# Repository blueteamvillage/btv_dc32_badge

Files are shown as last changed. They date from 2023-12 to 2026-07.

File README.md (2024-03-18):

# btv_dc32_badge

BTV DC32 Badge Artifacts

This is a DEFCON Indie badge created for DC32.

This is where all the files for the BTV DC32 Badge will be stored.

This includes code and art and cad and fab files.  All the things.

## File Structure

This is the file structure of this repository

* [/](/README.md) - YOU ARE HERE
* [/art/](./art/) - Artwork and other graphics created by this project
  * [/art/inspiration/](./art/inspiration/) - Art and graphics pulled f6 other sources used as inspiration for this project
  * [/art/fonts/](./art/fonts/) - Fonts used in art and graphics
* [/code/](./code/) - All project related Code / Firmware
* [/docs/](./docs/) - Documentation created by this project including web pages
* [/eda/](./eda/) - Electronic Design Automation files (i.e. KiCad)
  * [/eda/camera_badge/](./eda/camera_badge/) - KiCad 7.x project folder for the camera_badge PCB
* [/reference_parts/](./reference_parts/) - Documentation pulled from other sources related to components
* [/README.md](/README.md) - This File
* [/LICENSE](/LICENSE) - Currently set to MIT

Note: the reference_parts directory is a link to a submodule repository.
To add it use the following cmd after cloning this:
```
git submodule update --init --recursive
```
If adding for the first time (i.e., it is not linked in the remote master) use this:
```
git submodule add https://github.com/gowenrw/reference_parts reference_parts
```
This will make a link to the current commit of that repo.
To update it to a newer commit after its been added use this cmd:
```
git submodule update --remote
```

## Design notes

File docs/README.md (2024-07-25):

# BTV Camera Badge

BTV Camera Badge Repository web page and documentation.

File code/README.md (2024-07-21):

# Code

This is where all the project related Code / Firmware is located

# File Structure

This is the file structure of this repository

* [/](/README.md) - Home
* [/code/](/code/) - YOU ARE HERE

# Arduino IDE/CLI

The code presented here is mostly Arduino code.

In order to use this code and push new code to the ESP32 on the badge we recommend using the Arduino IDE/CLI software.
This can be downloaded for various platforms at [arduino.cc](https://www.arduino.cc/en/software).

The Arduino IDE UI will require some manual configuration to work with the badge ESP32 and our code.

The Arduino CLI can be used instead and allows for scripting much of the initial setup and use of whichever IDE you like (in my case I use VSCode).

# Arduino Versions

These are the Arduino IDE and CLI versions we have tested the code with:

* Arduino IDE v 2.3.2
  * [Windows MSI Link](https://downloads.arduino.cc/arduino-ide/arduino-ide_2.3.2_Windows_64bit.msi)
  * [Linux 64bit AppImage Link](https://downloads.arduino.cc/arduino-ide/arduino-ide_2.3.2_Linux_64bit.AppImage)
  * [MacOS ARM64bit DMG Link](https://downloads.arduino.cc/arduino-ide/arduino-ide_2.3.2_macOS_arm64.dmg)
  * [Installation Instructions](https://docs.arduino.cc/software/ide-v2/tutorials/getting-started/ide-v2-downloading-and-installing)
* Arduino CLI v 0.35.3
  * [Windows MSI Link](https://github.com/arduino/arduino-cli/releases/download/v0.35.3/arduino-cli_0.35.3_Windows_64bit.msi)
  * [Linux 64bit Tarball Link](https://github.com/arduino/arduino-cli/releases/download/v0.35.3/arduino-cli_0.35.3_Linux_64bit.tar.gz)
  * [MacOS ARM64bit Tarball Link](https://github.com/arduino/arduino-cli/releases/download/v0.35.3/arduino-cli_0.35.3_macOS_ARM64.tar.gz)
  * [Installation Instructions](https://arduino.github.io/arduino-cli/0.35/installation/)

WARNING - DO NOT use Arduino CLI v 1.x if you want the scripts here to work, it is very buggy concerning local config files and relative paths

# Quickstart

If you want to jump right in and start compiling and uploading code using the Arduino CLI and the scripts provided then checkout the [QUICKSTART page](QUICKSTART.md).

# Arduino IDE setup and use

Some additional setup is required to use the Arduino IDE with the ESP32 on the badge:

* Add the ESP32 boards manager URL in preferences
  * Under File->Preferences find the "Additional boards manager URLs" section and add the following
  * https://espressif.github.io/arduino-esp32/package_esp32_index.json
  * Then click OK and close the IDE.  When it is reopened it wil download the ESP32 board definitions.
* Select the board "ESP32 Dev Module"
  * You need to select a board to associate with the code even if that board is not connected
  * In the "Select Board" dropdown, choose "ESP32 Dev Module" from the list
  * The first time you do this it may download some addiotional software.
* Connect the ESP32 via USB cable and select the COM port if it is not autodetected
  * In most cases it should autodetect the port
  * Sometimes on first connect you need to help it by going to Tools->Port and choosing the port
* This code exceeds the normal partition size so make sure you select the Minimal SPIFFS Partition type
  * This setting can be found under Tools -> Partition Scheme
* This code uses the AdaFruit NeoPixel library which needs to be installed
  * The library can be installed via the Arduino IDE library manager or manually
  * Installation instructions can be found at [the adafruit neopixel github page](https://github.com/adafruit/Adafruit_NeoPixel)

Once the Arduino IDE environment has been set up you can simply open one of the sketches here, make whatever changes you like, then compile and upload the code to the badge.

# Arduino CLI

In an effort to bring portability to the code here (since this is lacking in the Arduino 2.x IDE) we will be providing a local configuration file for the Arduino CLI and scripts to make use of it.

While we cannot ensure this will work on all systems, the files provided should at a minimum help you configure your local environment.

## Using the CLI Local Config

The arduino cli will use a global default config if a config file is not specified.

A local config file is provided named ```arduino-cli.yml``` which uses relative path references for the data and staging and build and user area that Arduino CLI should use.

These directories are local to the repository code directory and the CLI will install all its needed files here instead of in the various places it usually defualts to on differnt systems.

While this might duplicate many files on your system if they are already installed in default locations, it provides a consistent cross platform way of knowing exactly what libraries, headers, etc., that Arduino will use in the compilation of your code.

NOTE that the .gitignore for this repository has been set up to ignore the local directories used to store the core and library files to prevent these files from accidentally getting uploaded to github.

To use the Arduino CLI with this local config file simply add the ```--config-file arduino-cli.yml``` argument to each CLI command.

For example, the command below uses the local config file and will dump the current config to the screen
```
arduino-cli --config-file arduino-cli.yml config dump
```

## Setup for CLI

There are a few things that need to be done to setup the Arduino CLI for use with the badge ESP32 and our code.

The ESP32 board core files must be loaded as well as any libraries the code will use.

To simplify this setup we have created setup bash script named ```cli-setup.sh``` that can be run on Linux and Windows (via Git Bash for Windows).

To perform the CLI setup via the script execute it in the code directory
```
bash ./cli-setup.sh
```

This script will save any std_out and std_err output to a file named ```arduino_cli_setup.log``` which you can review if you are having issues.

To perform the CLI setup manually without this script you can use the commands outlined below.

### Installing the ESP32 board core for CLI

Since the config is specifying a third party core for the ESP32 we need to pull an initial index from it.  This search command will pull that index.
```
arduino-cli --config-file arduino-cli.yml core search esp32
```

Next we need to install the ESP32 board core files using this command.
```
arduino-cli --config-file arduino-cli.yml core install esp32:esp32
```

If the ESP32 board core files were already installed the above will simply say already installed.

To update the core file indexs to check for newer versions of previously installed cores, use the following command
```
arduino-cli --config-file arduino-cli.yml core update-index
```

To upgrade any previously installed cores use the following command
```
arduino-cli --config-file arduino-cli.yml core upgrade
```

### Installing the Neopixel Library

This code uses the AdaFruit NeoPixel library which needs to be installed

If this is the first time we are installing a library we will need the indexes so this search command will get them
```
arduino-cli --config-file arduino-cli.yml lib search 'Adafruit NeoPixel'
```

Next we need to install the Adafruit NeoPixel library files with this command
```
arduino-cli --config-file arduino-cli.yml lib install 'Adafruit NeoPixel'
```

If the Adafruit NeoPixel library files were already installed the above will simply say already installed.

To upgrade a previously installed version of this library use the following command
```
arduino-cli --config-file arduino-cli.yml lib upgrade 'Adafruit NeoPixel'
```

### Installing Other Libraries

In addition to the Neopixel Library above the CTF portion of our code requires a few more libraries.

These should be installed using the same steps as above.

This is the list of additional libraries needed

* "AsyncTCP"
* "ESPAsyncWebSrv"
* "DNSServer"

## Connect badge ESP32 board via CLI

The following command will dump a list of all available board cores installed
```
arduino-cli --config-file arduino-cli.yml board listall
```

Make sure the ESP32 we are using on the badge is in that list
```
  ESP32 Dev Module                 esp32:esp32:esp32
```

If it is not then retry the CLI setup to install the core files.

Next we will connect the badge ESP32 to our machine using a USB C cable
and check if the CLI can see it.

The following command will list all the connected boards the CLI sees
```
arduino-cli --config-file arduino-cli.yml board list
```

This will show the detected COM port and board type (which may be Unknown)
```
  Port Protocol Type                Board Name FQBN Core
  COM4 serial   Serial Port (USB)   Unknown
```

Don't worry if the board FQBN shows up as Unknown since we can set that

Take note of the COM port since we will need that to communicate with it later

## Compile code via CLI

At this point we should be ready to compile and upload code to the badge ESP32 board.

In the following examples we will be referencing the sketch ```camera_badge_rev01``` code so you will need to change this for whichever sketch you wish to use.

The following command will compile the named sketch for use with our board fqbn
```
arduino-cli --config-file arduino-cli.yml compile --fqbn esp32:esp32:esp32 --build-path _build --export-binaries camera_badge_rev01 --build-property build.partitions=min_spiffs --build-property upload.maximum_size=1966080
```

The arg ```--build-path _build``` is optional to have it put all build artifacts here instead of temp for ease of troubleshooting.

The arg ```--export-binaries``` will save the final binary files into ```<sketch_name>/build/<fqbn>/``` for use by upload.

The build property args ```--build-property build.partitions=min_spiffs --build-property upload.maximum_size=1966080``` make sure that the partition size and upload size are set properly.
Our code is THIC and wont fit in the default partition size.

When the CLI compile is run it should show you compile stats and/or errors similar to this
```
  Sketch uses 1827197 bytes (92%) of program storage space. Maximum is 1966080 bytes.
  Global variables use 48884 bytes (14%) of dynamic memory, leaving 278796 bytes for local variables.
  Maximum is 327680 bytes.
  Used library        Version Path
  Adafruit NeoPixel   1.11.0  .\code\libraries\Adafruit_NeoPixel
  WiFi                2.0.0   .\code\_data\packages\esp32\hardware\esp32\2.0.11\libraries\WiFi
  AsyncTCP            1.1.4   .\code\libraries\AsyncTCP
  DNSServer           2.0.0   .\code\_data\packages\esp32\hardware\esp32\2.0.11\libraries\DNSServer
  ESPAsyncWebSrv      1.2.6   .\code\libraries\ESPAsyncWebSrv
  FS                  2.0.0   .\code\_data\packages\esp32\hardware\esp32\2.0.11\libraries\FS
  Used platform Version Path
  esp32:esp32   2.0.11  .\code\_data\packages\esp32\hardware\esp32\2.0.11
```

### Script to Compile code via CLI

To simplify the above we have created a bash script named ```cli-compile.sh``` that takes a single command line argument of the sketch name.

To perform the compile via the script execute it in the code directory
```
bash ./cli-compile.sh camera_badge_rev01
```

## Upload code via CLI

Now we are ready to upload the binary we compiled to the badge ESP32 board.

Note that the binary file needed is saved to ```<sketch_name>/build/<fqbn>/``` and will be named ```<sketch_name>.ino.bin```
The code we have written here may include binaries which can be used without compiling and if you make changes and compile then these files should be overwritten.

The following command will upload the named sketch binary to the badge
```
arduino-cli --config-file arduino-cli.yml upload -p COM4 --fqbn esp32:esp32:esp32 --input-file camera_badge_rev01/build/esp32.esp32.esp32/camera_badge_rev01.ino.bin
```

NOTE: Saving the compiled binary in a defined place and uploading from an input file allows for quickly changing between different code without the need to compile each again.

It should show you upload stats and/or errors
```
  esptool.py v4.5.1
  Serial port COM4
  Connecting....
  Chip is ESP32-D0WD-V3 (revision v3.0)
  Features: WiFi, BT, Dual Core, 240MHz, VRef calibration in efuse, Coding Scheme None
  Crystal is 40MHz
  MAC: a8:42:e3:47:f0:50
  Uploading stub...
  Running stub...
  Stub running...
  Changing baud rate to 921600
  Changed.
  Configuring flash size...
  Flash will be erased from 0x00001000 to 0x00005fff...
  ...
  Compressed 18960 bytes to 13073...
  Writing at 0x00001000... (100 %)
  Wrote 18960 bytes (13073 compressed) at 0x00001000 in 0.3 seconds (effective 538.9 kbit/s)...
  Hash of data verified.
  ...
  Compressed 732656 bytes to 475614...
  Writing at 0x00010000... (3 %)
  Writing at 0x0001c1bd... (6 %)
  ...
  Writing at 0x000bcec0... (96 %)
  Writing at 0x000c2b72... (100 %)
  Wrote 732656 bytes (475614 compressed) at 0x00010000 in 6.3 seconds (effective 925.8 kbit/s)...
  Hash of data verified.
  Leaving...
  Hard resetting via RTS pin...
```

### Script to Upload code via CLI

To simplify the above we have created a bash script named ```cli-upload.sh``` that takes two command line arguments of the sketch name and serial port.

To perform the compile via the script execute it in the code directory
```
bash ./cli-upload.sh camera_badge_rev01 COM4
```

## Monitor Serial Output

To monitor the serial output you can use the arduino-cli or your favorite serial app.

The following command will list all the connected boards so you can get the serial port
```
arduino-cli --config-file arduino-cli.yml board list
```

The arduino-cli monitor command with serial port (from above) and baud config can be used like this:
```
arduino-cli monitor --port COM4 --config baudrate=115200
```

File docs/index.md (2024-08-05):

---
layout: default
---

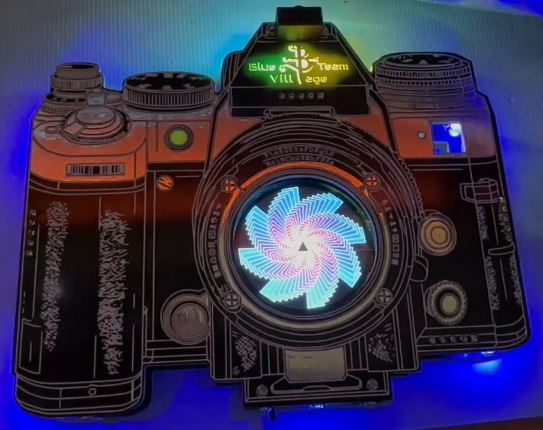
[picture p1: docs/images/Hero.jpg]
Hero Image


# BTV Camera Badge

Welcome to the BTV Camera Badge website.

This badge was designed for the DEFCON 32 security conference in August 2024.

On this page you will find all the details about this badge including an operations guide, an assembly guide (for those building the badge from a kit), and a detailed review of the art and cicuit design and pcb design.

---

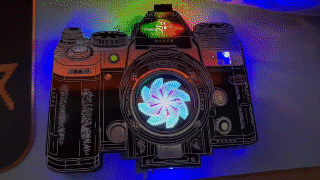
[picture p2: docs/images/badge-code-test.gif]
Code Test Image


# Details

[Assembly instructions can be found here](BadgeInstructions.md)

More detailed information about the project COMING SOON.

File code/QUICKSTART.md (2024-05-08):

# Code Quickstart

Notes:

* You will need Arduino CLI Installed and a Bash shell (on Windows Git Bash is provided by Git for Windows)
* The CTF code is a precompiled library so you cant change that for now, source to be released after defcon
* The current code that is loaded on the badge is the sketch named ```camera_badge_rev01```

## Setting up Arduino CLI environment

Follow these steps:

* Change directory to the code directory if you arent already there
* Run the following command preceding it with ```bash``` if needed by your OS
  * ```./cli-setup.sh```
* If it completes without errors then setup is complete
  * If you have errors then refer to the main README doc or script file to try the steps manually

## Compiling Code

Once you have made whatever changes you wanted to the code here is how we compile it.

* Change directory to the code directory if you arent already there
* Run the following command preceding it with ```bash``` if needed by your OS changing the sketch name if needed
  * ```./cli-compile.sh camera_badge_rev01```
* If it completes without errors then the compile is complete
  * If you have errors then read what they are and make the appropriate changes to your code

## Upload Code

Once the code has been compiled we can upload it to the badge.

Follow these steps:

* Change directory to the code directory if you arent already there
* Run the following command
  * ```arduino-cli --config-file arduino-cli.yml board list```
* Take note of the serial port name of the connected board 
* Run the following command preceding it with ```bash``` if needed and changing the serial port to above
  * ```./cli-upload.sh camera_badge_rev01 COM6```

## Serial Monitor

Once the code has been uploaded you can use the serial monitor to look for any text the code is sending.

* Run the following command changing the serial port to what board list showed above
  * ```arduino-cli monitor --config baudrate=115200 --port COM6```
* On Linux
  * ```arduino-cli --config-file arduino-cli.yml monitor --config baudrate=115200 --port /dev/ttyUSB0```

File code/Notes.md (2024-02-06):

Docs for the 1.28in round display

https://www.waveshare.com/wiki/1.28inch_LCD_Module

Video

https://www.youtube.com/watch?v=k2c2zCmC_X0&ab_channel=DroneBotWorkshop

Code screen_poc_01 uses waveshare example code

vcc 3.3v
gnd
scl 18
sda 23
dc 16
cs 5
rst 4

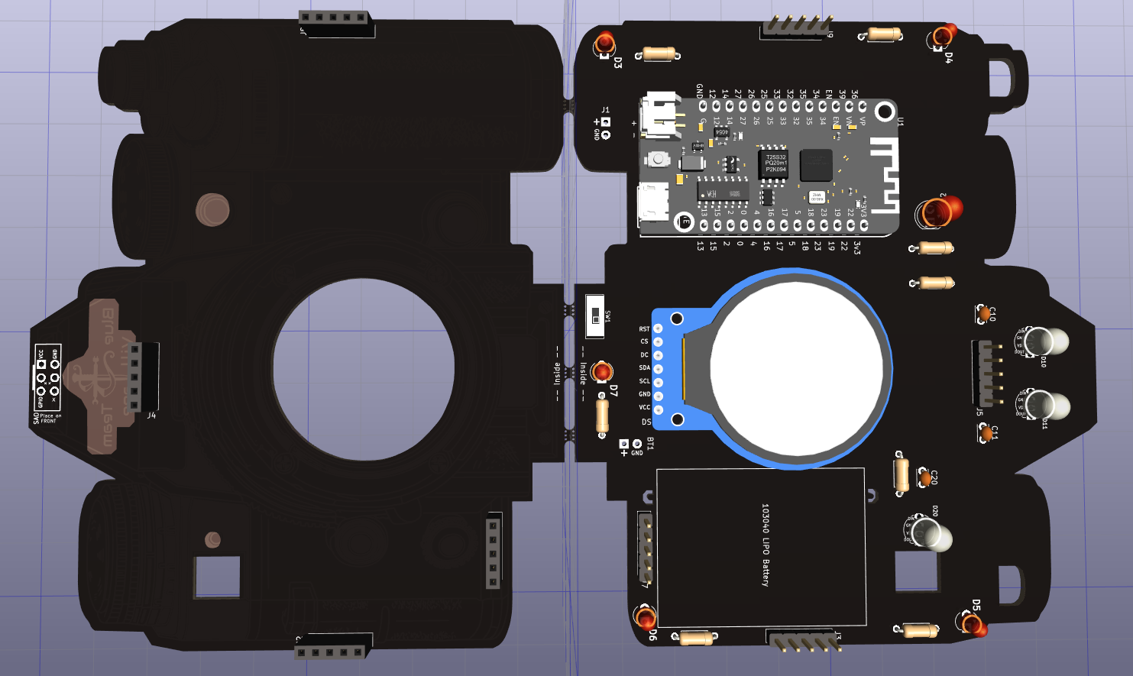
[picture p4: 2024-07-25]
docs/images/prototype-image03.png

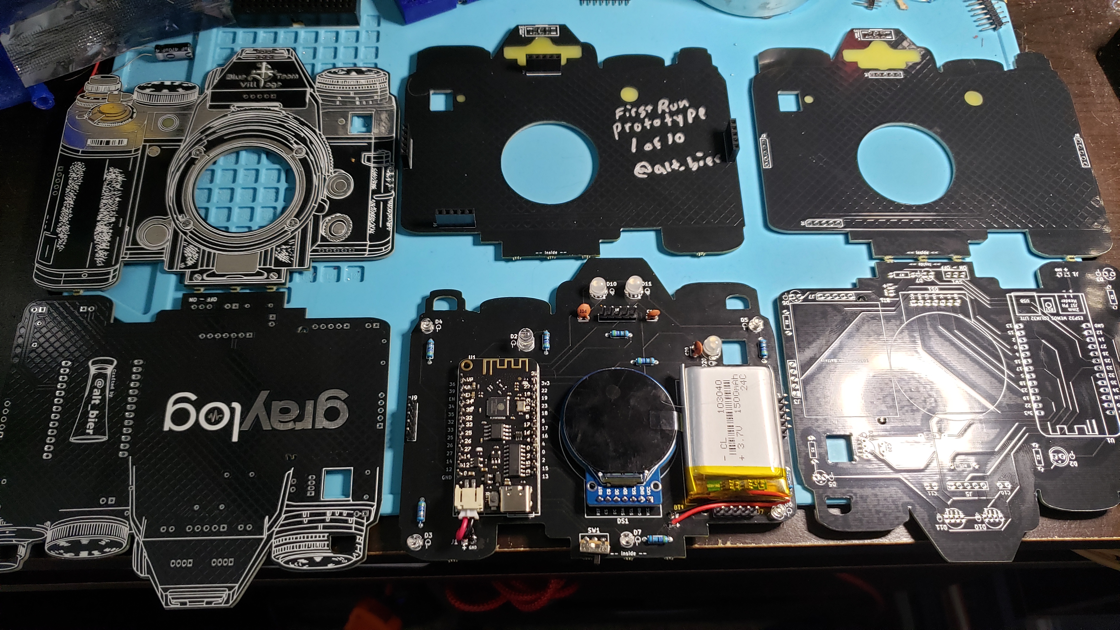
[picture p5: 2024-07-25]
docs/images/prototype-image04.jpg

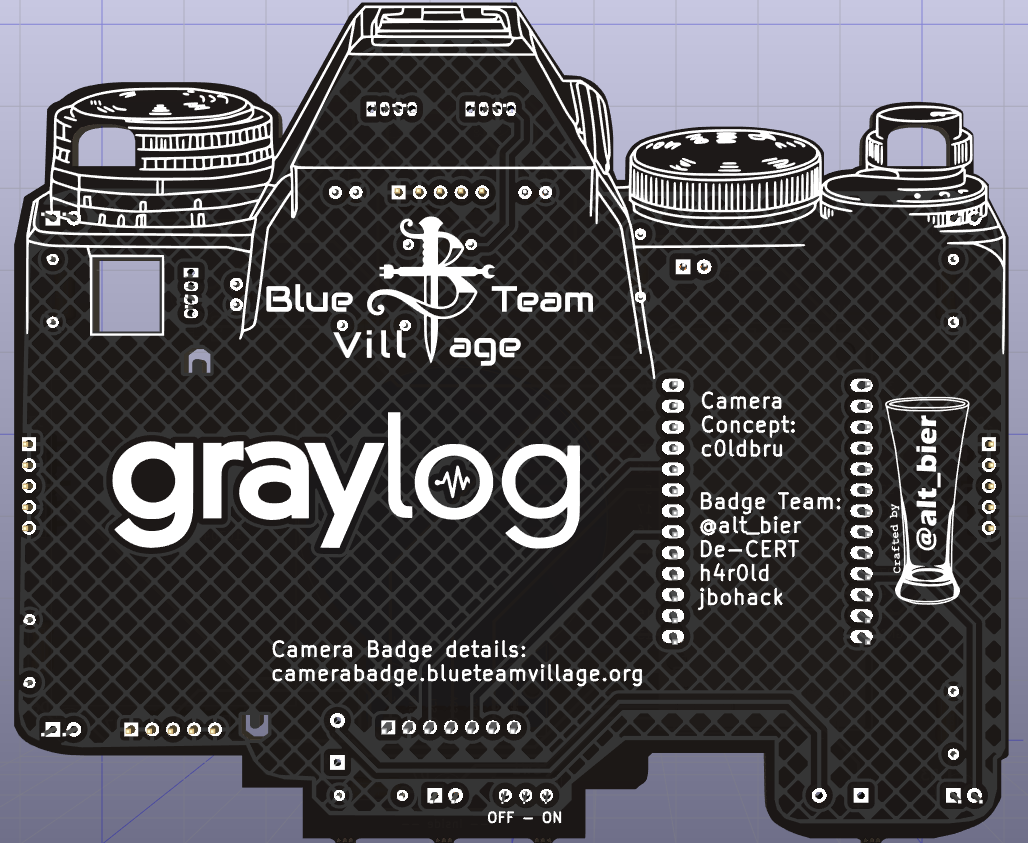
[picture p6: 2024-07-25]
docs/images/prototype-image02.png

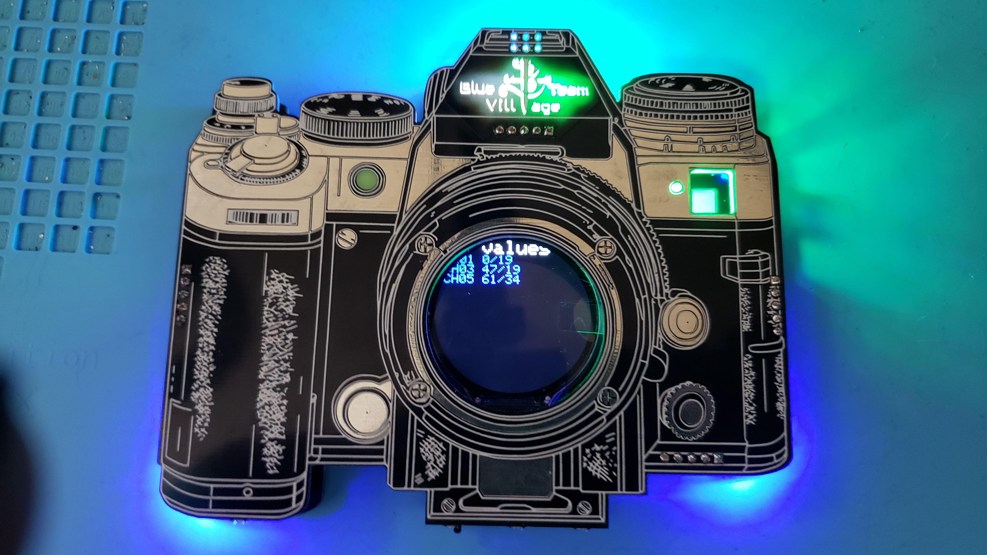
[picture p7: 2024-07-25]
docs/images/prototype-image05.jpg

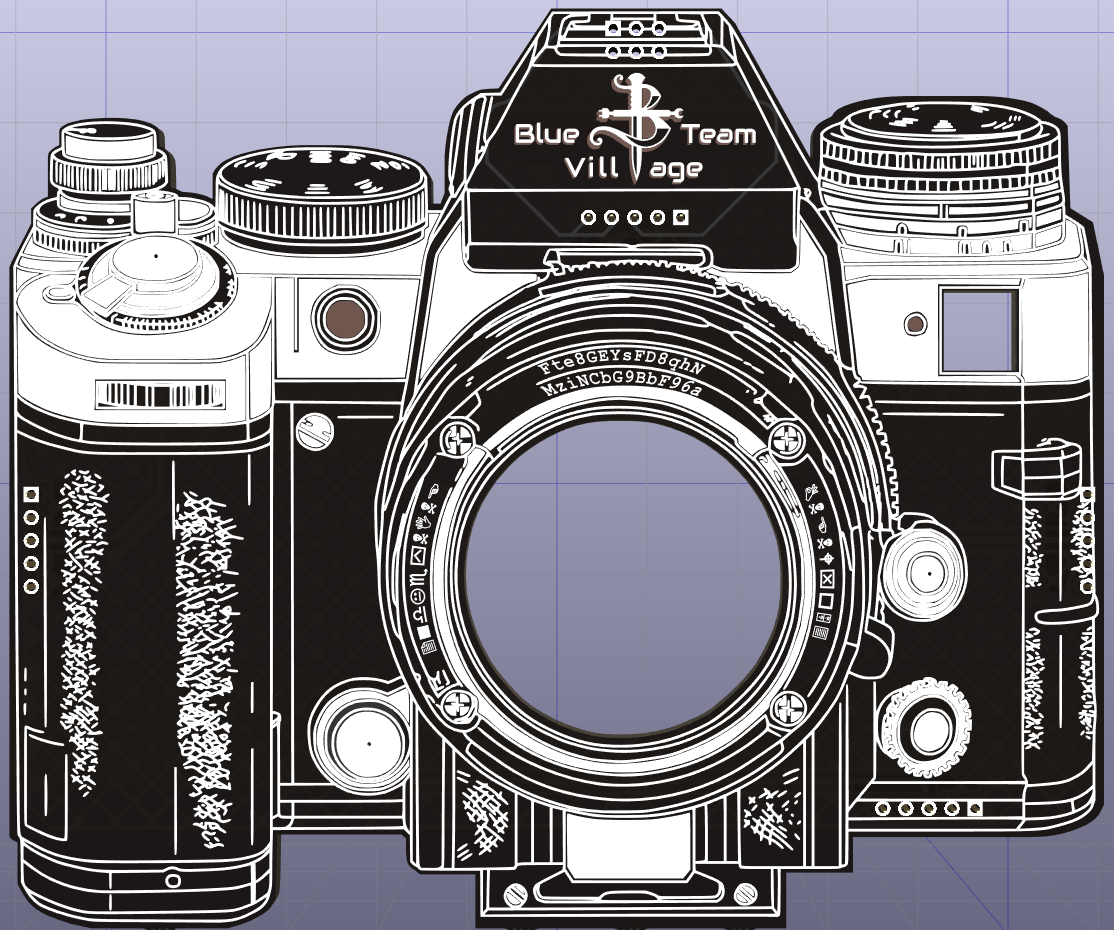
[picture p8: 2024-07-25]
docs/images/prototype-image01.png

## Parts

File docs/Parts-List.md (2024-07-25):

# Parts-List.md

## Screen [1 ea]

1.28 inch TFT LCD Display Module Round RGB 240*240 GC9A01 Driver 4 Wire SPI Interface

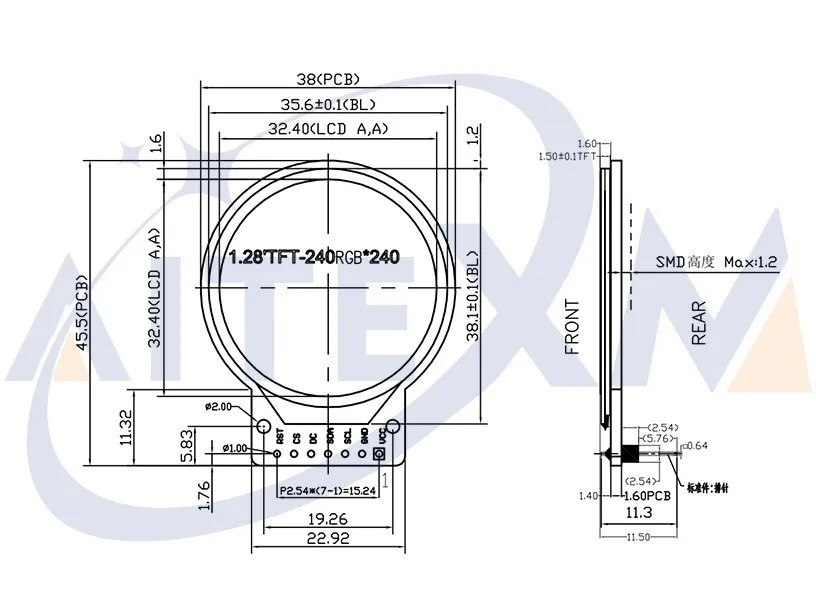
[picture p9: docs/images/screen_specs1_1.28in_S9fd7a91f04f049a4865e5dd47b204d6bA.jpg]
Specs1

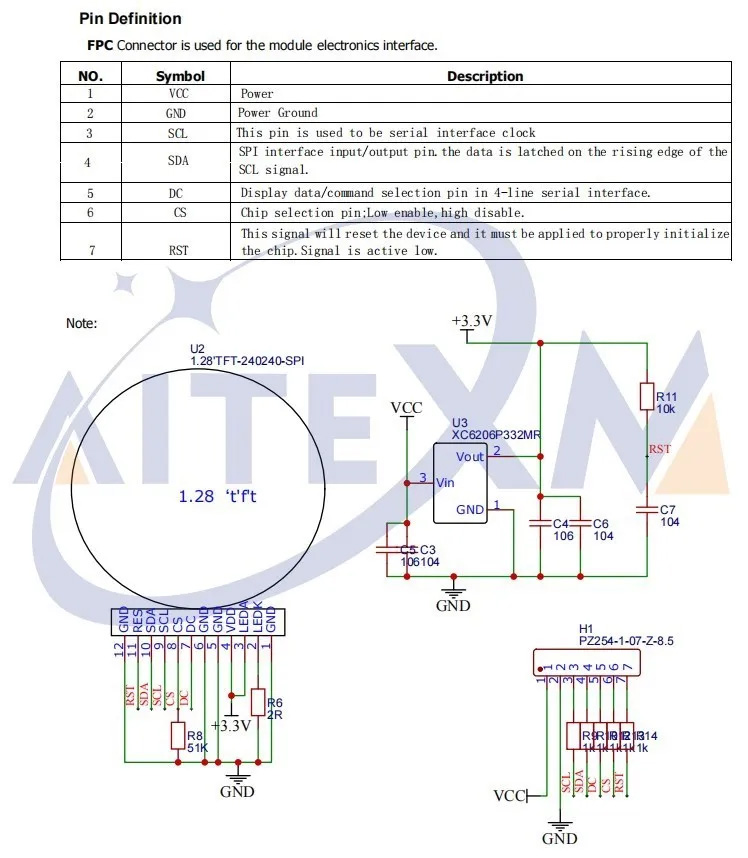
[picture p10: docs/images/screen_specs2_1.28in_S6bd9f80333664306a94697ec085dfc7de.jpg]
Specs2


https://www.amazon.com/Teyleten-Robot-Display-Interface-240x240/dp/B0B7TFRNN1

https://www.aliexpress.us/item/3256804295713253.html

## Dev Board with LIPO charge builtin [1 ea]

ESP32 Lite V1.0.0 Wifi Bluetooth Development Board ESP32 REV1 CH340G 4MB TYPE-C
NEW SMALLER CHIP and Dev Board includes LIPO connector and charge circuit

https://www.amazon.com/AITRIP-Bluetooth-Development-Antenna-MicroPython/dp/B0BCJXDYLY

https://www.aliexpress.us/item/3256804515306833.html

## Switch [1 ea]

Switch SS12D00 two position 3-pin 3mm handle

https://www.aliexpress.us/item/2255801021214741.html

## Addressable LEDs [3 ea]

WS2811 F5 5mm HAT housing

https://www.aliexpress.us/item/2251832645784910.html

## Blue LEDs [5 ea]

LED F3 3mm Ultra Bright Flat top Head BLUE Wide Angle Light Emitting Lamp Diodes

https://www.aliexpress.us/item/3256802346555541.html

## Resistors [8 ea]

Resistor 1/4W 47R 1% Metal film 47 ohm resistance

https://www.aliexpress.us/item/3256802343221323.html

## Capacitors [3 ea]

Capacitor 50V monolithic ceramic 100NF 104

https://www.aliexpress.us/item/3256802789853556.html

## Lipo Battery [1 ea]

3.7V 1200mAh Lithium Polymer LiPo Rechargeable Battery 103040

https://www.aliexpress.us/item/3256804282777660.html
https://www.aliexpress.us/item/3256805760800610.html

## Thin Adhesive strip [length to cut and place on all batteries]

Rolls of 36ft thin strong adhesive strip to secure battery in place.
Bought by the roll and cut into pieces that will be secured to battery before shipping.
Customer will just peel the film off the strip before sticking to the pcb.
Assuming 2in per battery one roll would do about 200 batteries.

https://www.amazon.com/gp/product/B09T6VCB4D

## Micro PH/JST connectors [1 ea]

PH2.0 Mini Micro JST 2.0 PH 2-Pin Plug With terminal Wires 26AWG
This is for connecting the dev board battery connection to the PCB.
If getting Lippo batteries with a connector this may not be needed (since it will be cut off and reused)

https://www.aliexpress.us/item/3256801804215866.html

## Male Headers [1 ea]

Header pins male 2.54in 1x40 breakaway

https://www.aliexpress.us/item/2251832803038195.html

## Female Headers [4 ea]

Header pins female 2.54in 1x5

https://www.aliexpress.us/item/2251832784633600.html

## SAO Connector (badge side) [1 ea]

Header female 2x3 6-pin with polarizing key

https://www.aliexpress.us/item/2251832874579437.html

## Bright White LED [1 ea]

Super Bright 5mm White LED clear bulbs

Note this is the only product in the list that I have not ordered previously so maybe shop around for this one --Richard

https://www.aliexpress.us/item/2251832644655195.html

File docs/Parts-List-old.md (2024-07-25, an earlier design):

# Parts-List.md

## Screen

2.4inch LCD Display Module 240×320 Resolution RGB Colors LCD Monitor 2.4" TFT Screen SPI Interface Board

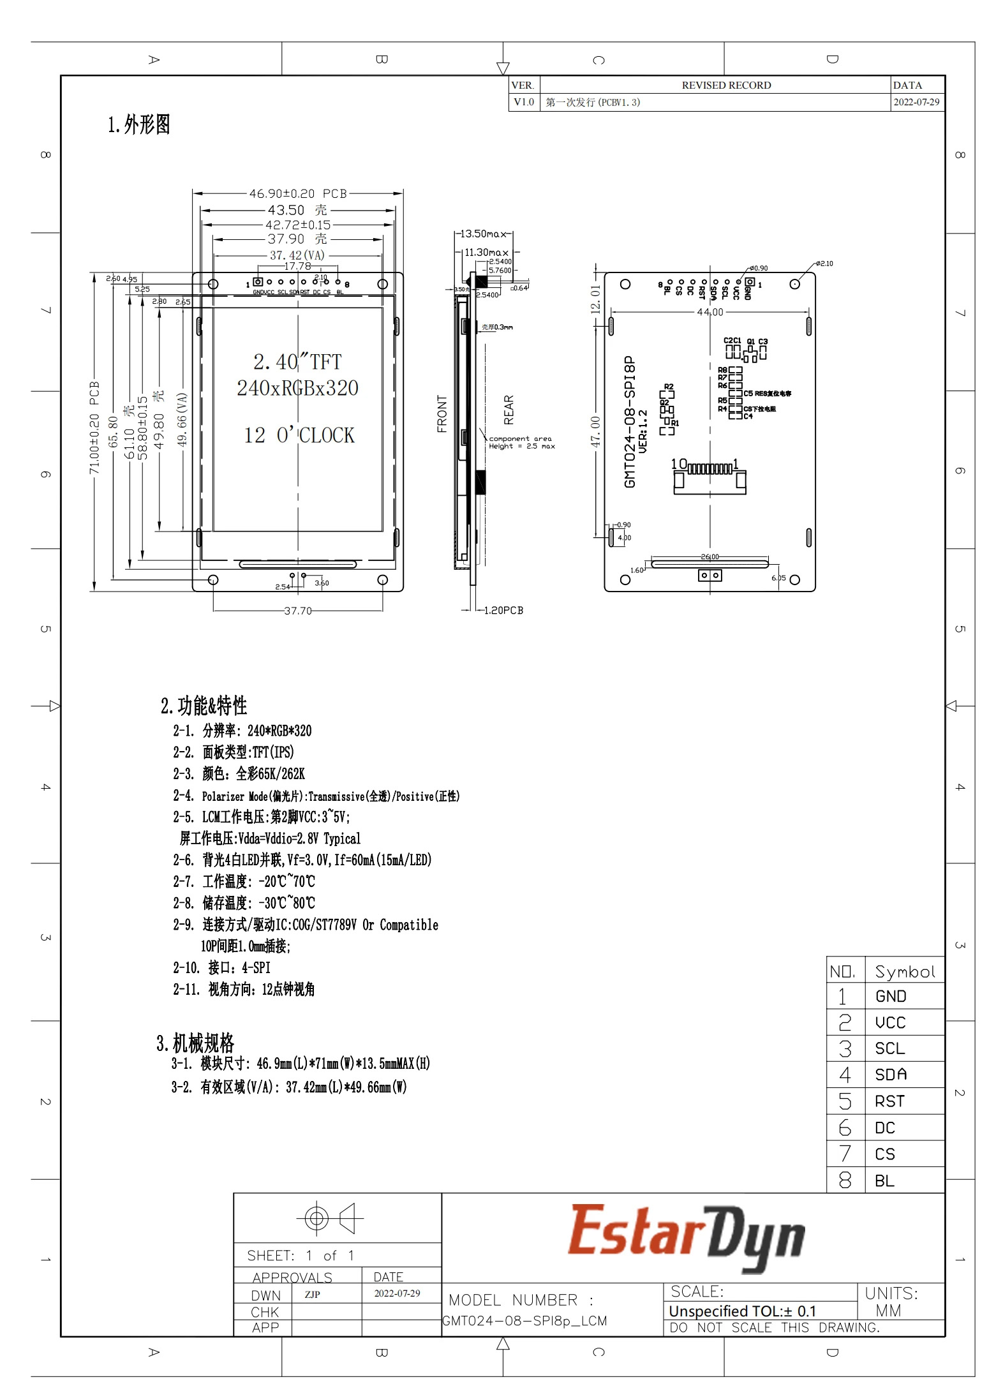
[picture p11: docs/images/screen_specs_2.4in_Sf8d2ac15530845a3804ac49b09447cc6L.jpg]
Specs


https://www.amazon.com/2-4inch-Display-240%C3%97320-Resolution-Interface/dp/B0CGDQN811

https://www.aliexpress.us/item/3256806123904425.html

https://www.aliexpress.us/item/3256805947033530.html

https://www.aliexpress.us/item/3256805989033289.html

1.28 inch TFT LCD Display Module Round RGB 240*240 GC9A01 Driver 4 Wire SPI Interface

Specs1
Specs2

https://www.amazon.com/Teyleten-Robot-Display-Interface-240x240/dp/B0B7TFRNN1

https://www.aliexpress.us/item/3256804295713253.html

https://www.aliexpress.us/item/3256806201295818.html

## Dev Board 

ESP32 Development Board TYPE-C WROOM-32 WiFi+Bluetooth BT+BLE MCU Module

https://www.amazon.com/gp/product/B0B19DXFHX/

https://www.aliexpress.us/item/3256805348040808.html

## Dev Board with LIPO builtin

ESP32 Lite V1.0.0 Wifi Bluetooth Development Board ESP32 REV1 CH340G 4MB TYPE-C
NEW SMALLER CHIP and Dev Board includes LIPO connector and charge circuit

https://www.amazon.com/AITRIP-Bluetooth-Development-Antenna-MicroPython/dp/B0BCJXDYLY

https://www.aliexpress.us/item/3256804515306833.html

ESP32-D0WDQ6 (and other QFN) Chip Specs:
https://www.mouser.com/datasheet/2/891/Espressif_Systems_01292021_esp32-1991551.pdf

## LIPO Charge Daughter Board

A small pcb to add on to the badge to perform LIPO battery charging using its own USB type C connector

https://www.amazon.com/dp/B0C2VD3ZW3

https://www.aliexpress.us/item/3256806158767195.html

## LIPO Boost Converter Daughter Board

A small pcb to add on to the badge to perform DC-DC voltage boost from the LIPO 3.7V battery (4.2V-3.2V) to 9V or 12V for the VIN on the ESP dev board

https://www.amazon.com/dp/B08M19C7MM

https://www.aliexpress.us/item/3256802672103106.html

This one may wrk better:
A small pcb to add on to the badge to perform DC-DC voltage boost from the LIPO to 5V for the VIN on the ESP dev board

https://www.amazon.com/gp/product/B08RJ8769R

https://www.aliexpress.us/item/2255799830473720.html

## Buttons

## LEDs

## Standoffs

## Battery

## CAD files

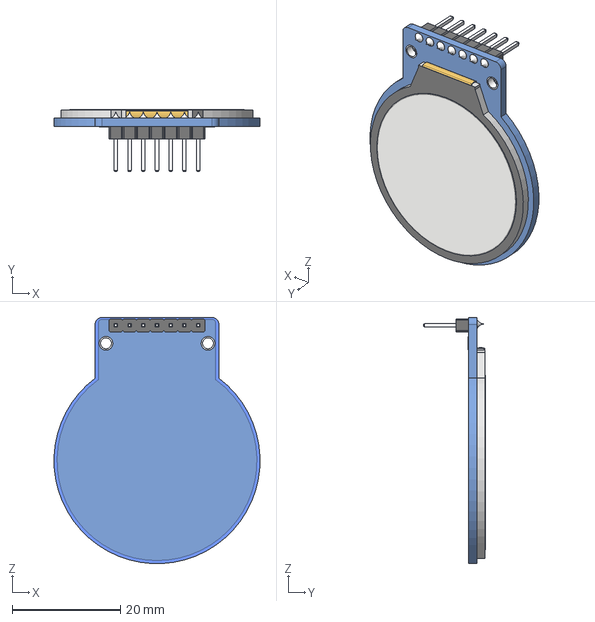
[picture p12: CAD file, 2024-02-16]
eda/camera_badge/3d_models/GC9A01_1.28IN_240x240_v1.step
38.1 x 11.5 x 45.5 mm

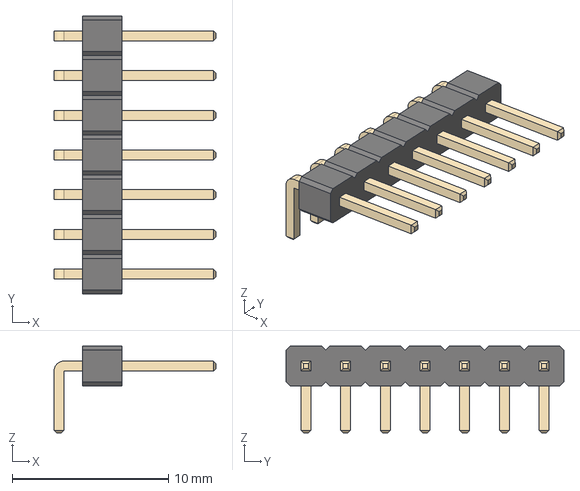
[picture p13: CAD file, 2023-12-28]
eda/camera_badge/3d_models/PinHeader_1x07_P2.54mm_Horizontal.step
10.4 x 17.8 x 5.54 mm

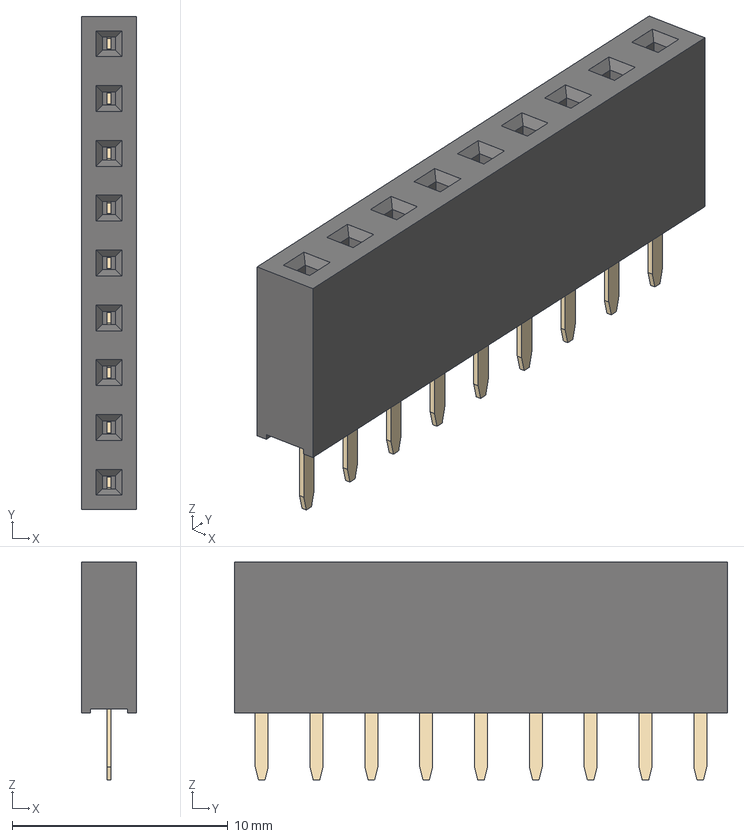
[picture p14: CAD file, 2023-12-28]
eda/camera_badge/3d_models/PinSocket_1x09_P2.54mm_Vertical.step
2.54 x 22.9 x 10.1 mm

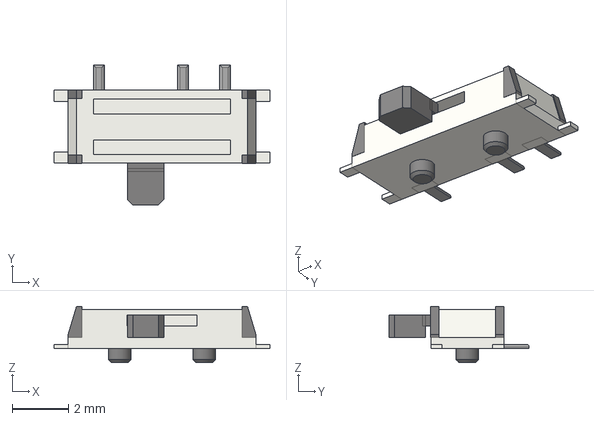
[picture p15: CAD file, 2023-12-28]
eda/camera_badge/3d_models/SW_SPDT_PCM12.step
7.70 x 5.00 x 2.00 mm

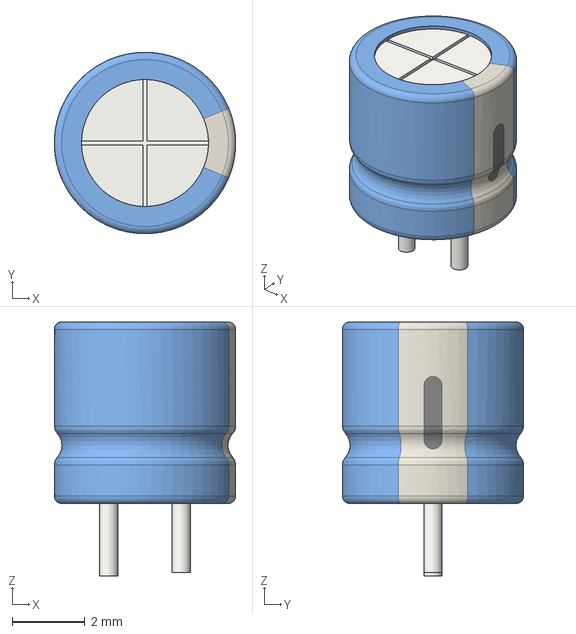
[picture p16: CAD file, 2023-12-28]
eda/camera_badge/3d_models/CP_Radial_D5.0mm_P2.00mm.step
5.00 x 5.00 x 7.00 mm

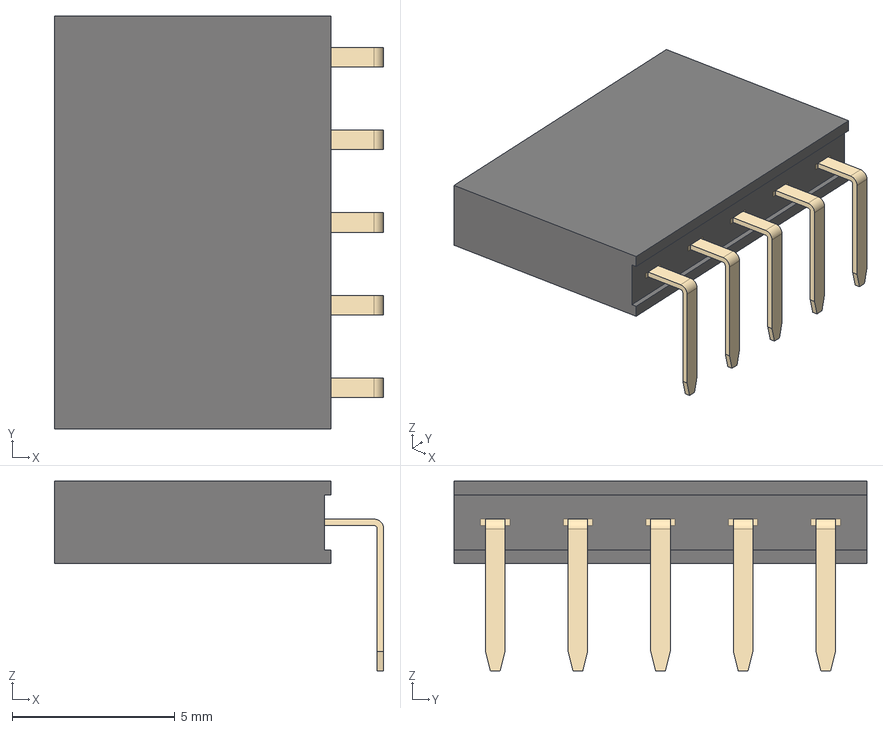
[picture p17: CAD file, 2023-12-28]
eda/camera_badge/3d_models/PinSocket_1x05_P2.54mm_Horizontal.step
10.1 x 12.7 x 5.84 mm

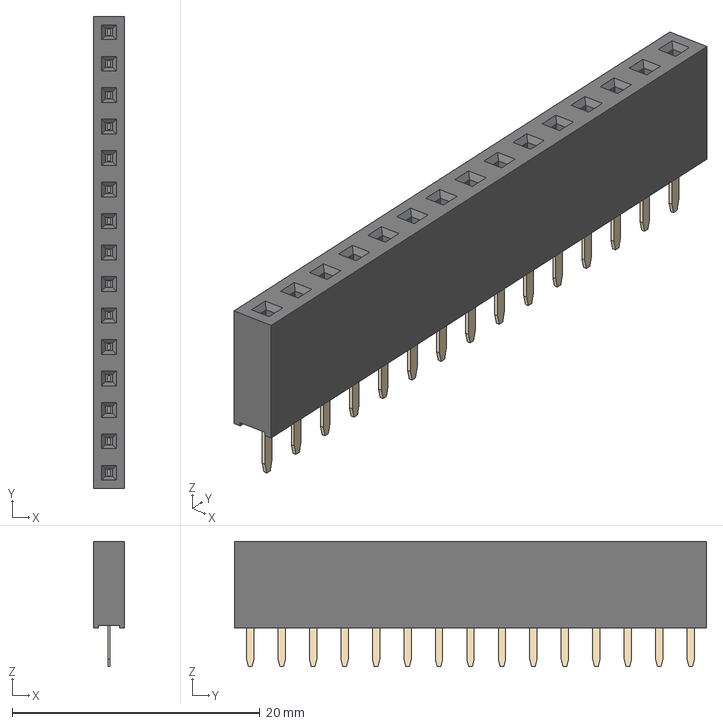
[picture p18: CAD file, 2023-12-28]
eda/camera_badge/3d_models/PinSocket_1x15_P2.54mm_Vertical.step
2.54 x 38.1 x 10.1 mm

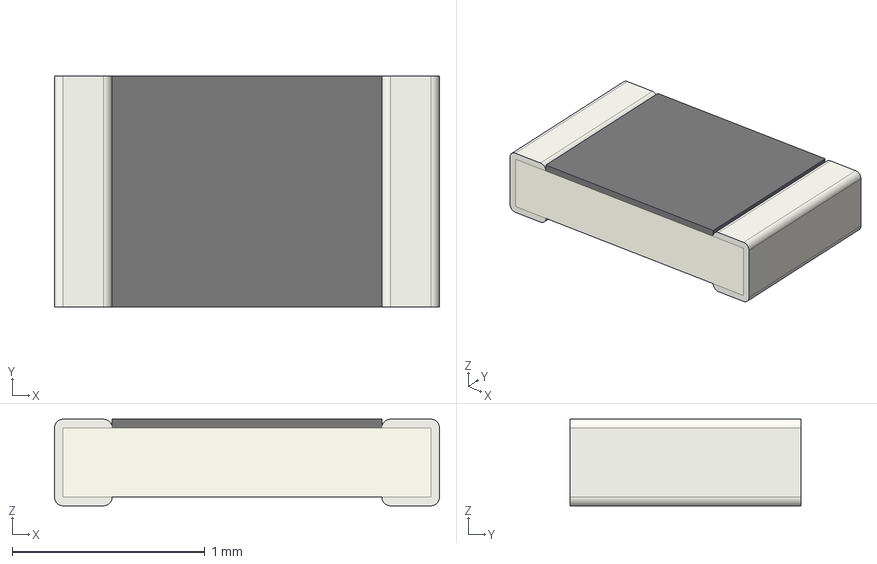
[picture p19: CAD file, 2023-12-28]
eda/camera_badge/3d_models/R_0805_2012Metric.step
2.00 x 1.20 x 0.45 mm

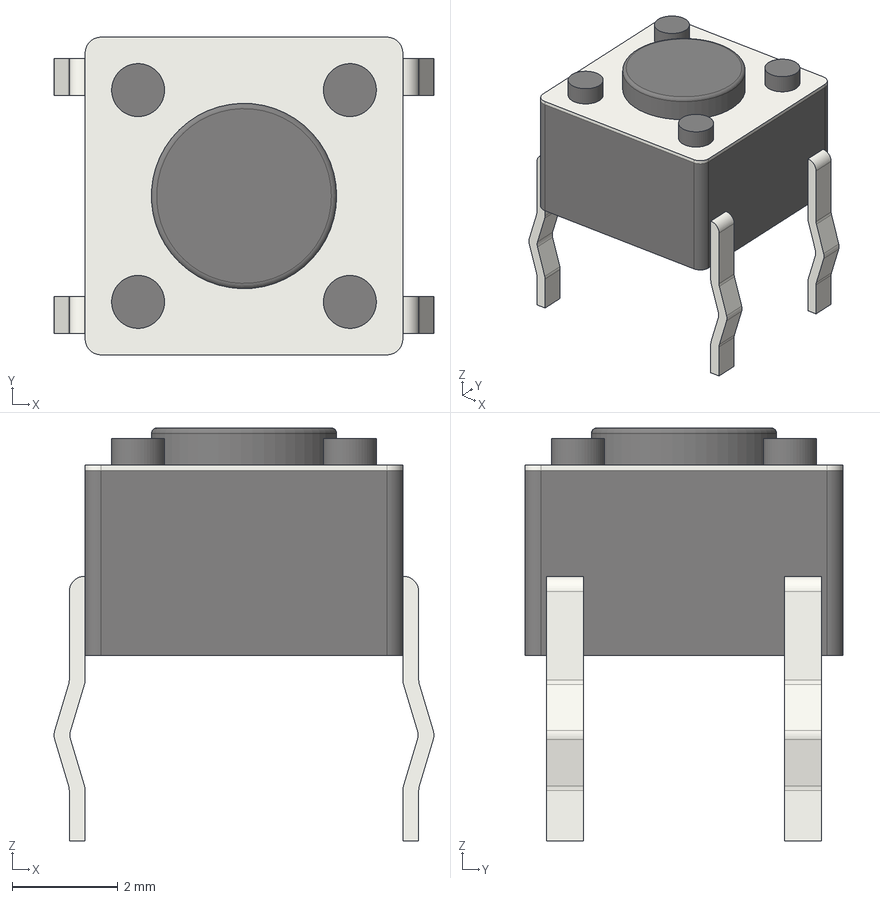
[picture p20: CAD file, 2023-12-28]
eda/camera_badge/3d_models/SW_PUSH_6mm.step
7.17 x 6.00 x 7.80 mm

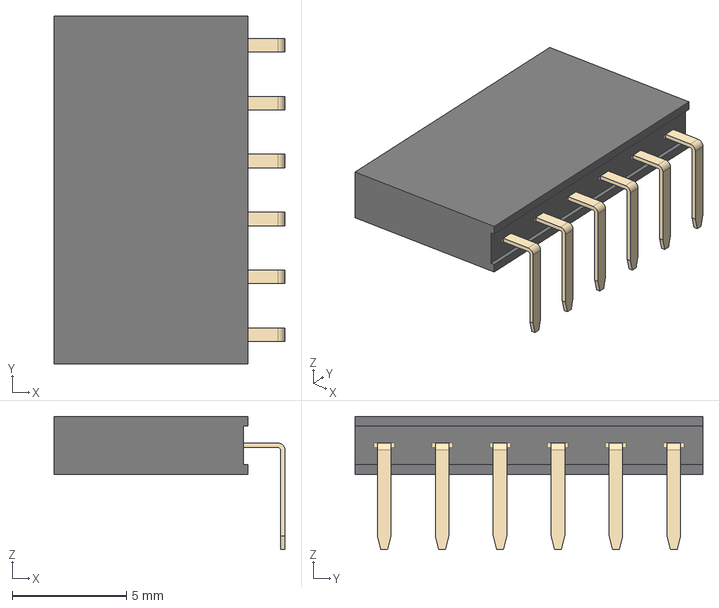
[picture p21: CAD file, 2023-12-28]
eda/camera_badge/3d_models/PinSocket_1x06_P2.54mm_Horizontal.step
10.1 x 15.2 x 5.84 mm

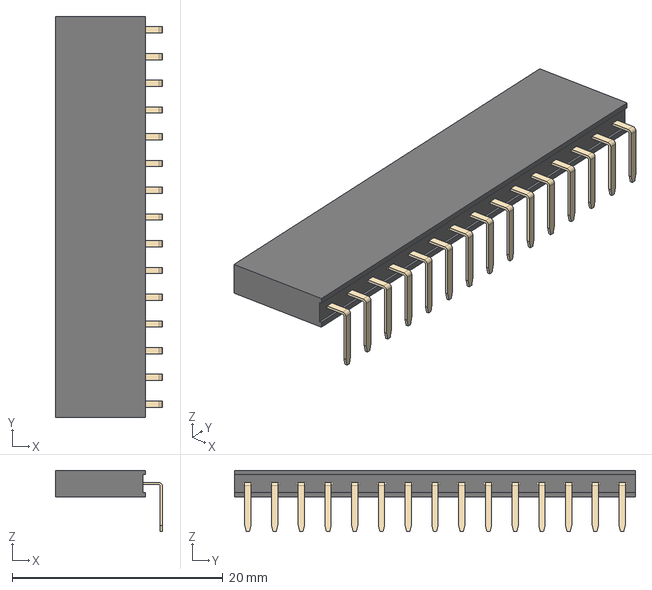
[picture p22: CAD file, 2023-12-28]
eda/camera_badge/3d_models/PinSocket_1x15_P2.54mm_Horizontal.step
10.1 x 38.1 x 5.84 mm

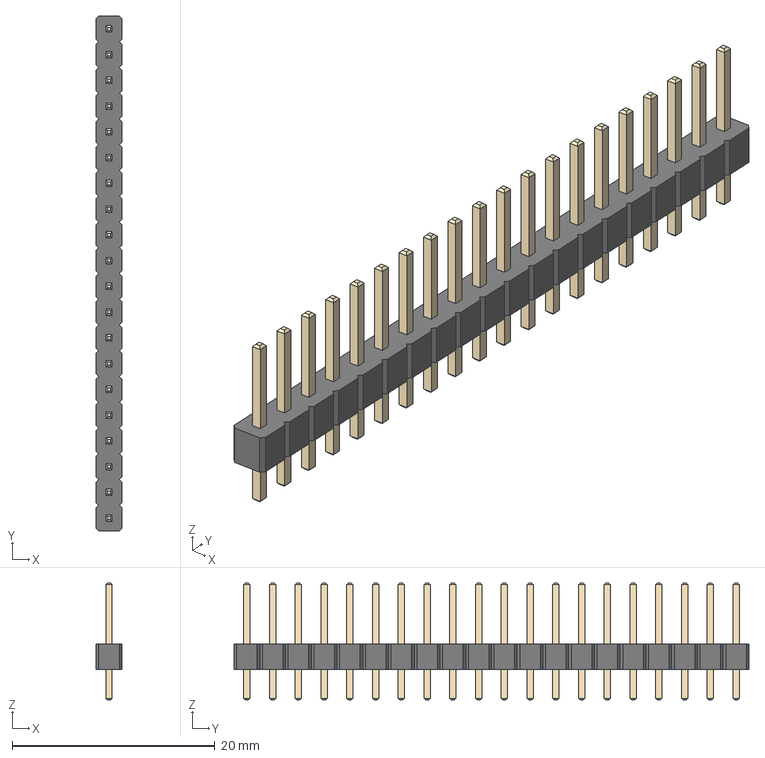
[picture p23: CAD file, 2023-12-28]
eda/camera_badge/3d_models/PinHeader_1x20_P2.54mm_Vertical.step
2.54 x 50.8 x 11.5 mm

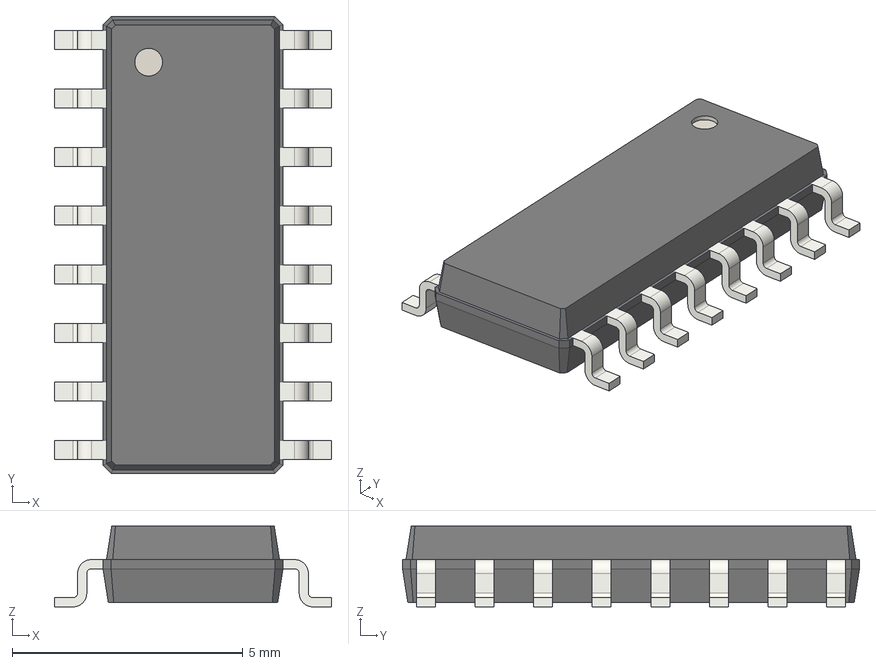
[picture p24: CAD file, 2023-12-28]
eda/camera_badge/3d_models/SOIC-16_3.9x9.9mm_P1.27mm.step
6.00 x 9.90 x 1.75 mm

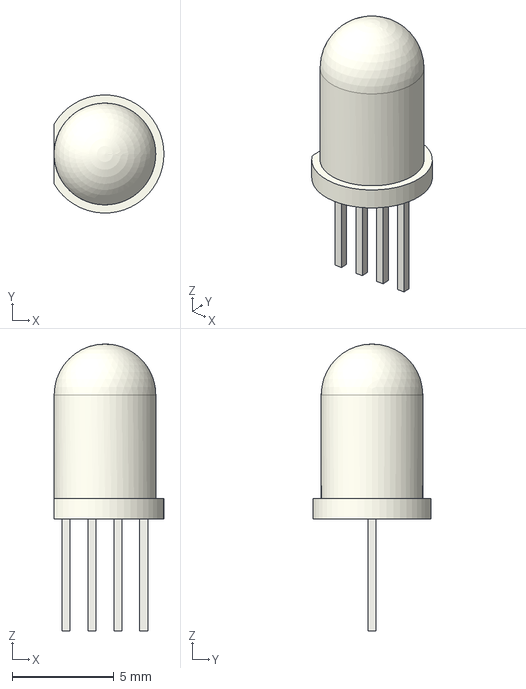
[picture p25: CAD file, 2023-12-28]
eda/camera_badge/3d_models/LED_D5.0mm-4_RGB_Neo.step
5.40 x 5.79 x 14.1 mm

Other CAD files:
eda/camera_badge/3d_models/PinSocket_1x04_P2.54mm_Vertical.step
eda/camera_badge/3d_models/PinHeader_1x01_P2.54mm_Vertical.step
eda/camera_badge/3d_models/SW_SS12D00G-Mini-SPDT-Slide-Switch-3pin-1P2T-2-Position-Toggle-Switch-3D.step
eda/camera_badge/3d_models/LED_0603_1608Metric.step
eda/camera_badge/3d_models/BatteryHolder_2466_1xAAA.step
eda/camera_badge/3d_models/BatteryHolder_2468_2xAAA.step
eda/camera_badge/3d_models/Battery_Holder_3xAAA_Simple.step
eda/camera_badge/3d_models/Battery_Holder_CR2032_BS-2-1.stp
eda/camera_badge/3d_models/CP_Radial_D6.3mm_P2.50mm.step
eda/camera_badge/3d_models/CUI_PXO7803-500-M-TR.step
eda/camera_badge/3d_models/C_0603_1608Metric.step
eda/camera_badge/3d_models/C_0805_2012Metric.step
eda/camera_badge/3d_models/C_1206_3216Metric.step
eda/camera_badge/3d_models/C_Disc_D3.0mm_W2.0mm_P2.50mm.step
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

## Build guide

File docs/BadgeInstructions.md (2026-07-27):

---
layout: default 
---

<!-- Links? -->

<!-- Image of Finished Badge here -->

# BTV Camera Badge Instructions

Read below for assembly instructions for the DefCon32 BTV Camera Badge.

## Component List

This is the list of components that you should have available for the assembly.

*  Camera Badge Kit Bag
	*  1x Top PCB board
	*  1x Bottom PCB board
    *  1x Screen
	*  1x ESP23 Dev Board /w LIPO connector
	*  1x 3-pin Switch
	*  3x Addressable LEDs
	*  5x Blue LEDs 
	*  1x Bright White LED 
	*  8x 47 Ohm resistors
	*  3x 50V Capacitors
	*  1x LIPO Battery 3.7V 1200mAh
		* 1x Thin Adhesive Strip for Battery
	*  1x Micro PH/JST Connector (This may be on the end of the battery cable)
	*  1x Male Header 1x40 breakaway
	*  4x Female Headers 1x5
	*  1x SAO Connector 2x3 6-pin with wrong-way prevention 

## Reference Photos

<!-- Picture Top  -->
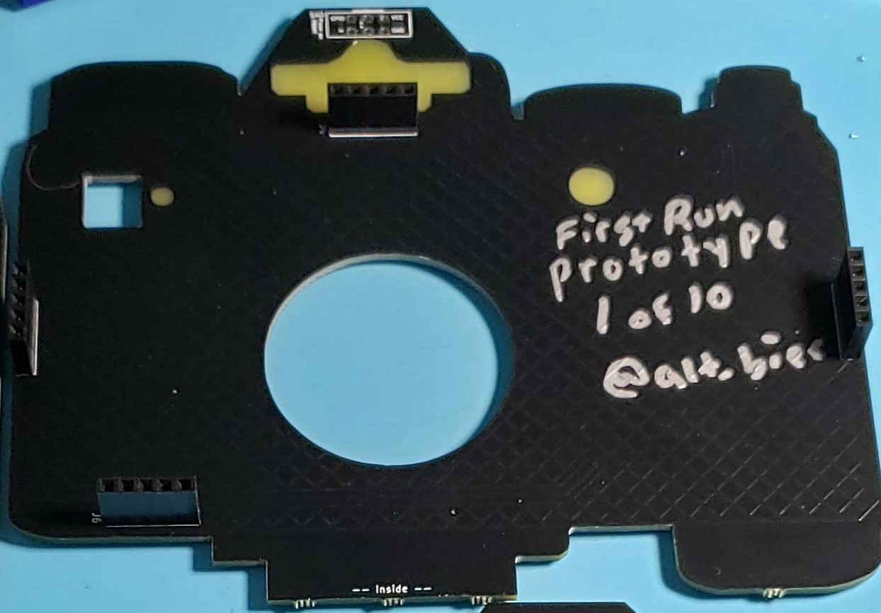
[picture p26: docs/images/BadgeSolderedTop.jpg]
Soldered PCB Top


This PCB will be referenced as the "Top PCB" in the following instructions

<!-- Picture Bottom -->
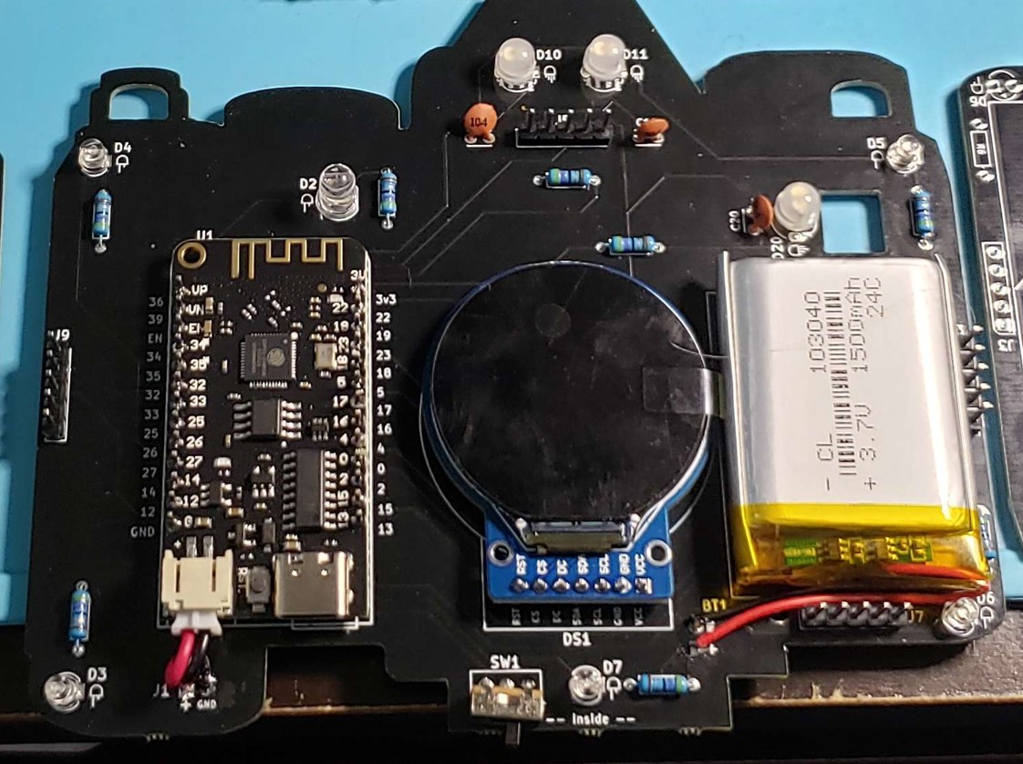
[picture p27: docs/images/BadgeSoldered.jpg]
Soldered PCB Bottom


This PCB will be referenced as the "Bottom PCB" in the following instructions

## Soldering Instructions

After ensuring you have all the parts lets begin soldering.  These steps are the listed in order to make things as convenient as possible.  Read the instruction under the part first before beginning to solder.

We will start with the bottom board of the badge please ensure the components themselves are on the inside of the badge as labeled on the center bottom of the PCB "-- Inside --"
*  Solder Resistors
	* There are 8 resistors and the locations are marked as a small rectangle with R# on the inside.  
	* Polarity does not matter for these.
* Solder Blue LEDs
	* There are five blue LEDs, these are the smaller two pin LEDs.  
	* They go into the circles with the D# label.  
	* Do NOT put a blue LED into the D2 location.  
	* Please note polarity listed under D# and the shown wire lengths match as shown on the board.
*  Solder Capacitors
	* There are three capacitors.
	* They go into the locations with the circles that have a line above and below the circles.
	* Their locations are marked as C10, C11, and C20.
	* Polarity does not matter for these.
*  Solder the Switch
	* The 3 pin switch goes into the location marked SW1.
	* To get the bend easily, place the switch onto board and mark where the wire go over the holes. Then use a flat edge to start the bend, and bend the wires to 90 degrees.
*  Solder Addressable LEDS
	* There are 4-pin Addressable LEDs.
	* These go into the circles marked D10, D11, and D20 on the board.
	* Polarity matters, ensure the wire lengths on the LED match the lengths shown on the board.
*  Solder the White LED
	* There is one larger 2 pin LED.
	* The white LED goes into the location marked D2.
	* Polarity matters, ensure the wire lengths on the LED match the lengths shown on the board.
*  Solder the 1x5 Male Header 
	* Take the male header 1x40 breakaway and create four 1x5 male Headers.
	* Solder these into the four rectangles marked J#.  
*  Solder the ESP32 board
	* Ensure the ESP32 board is placed correctly as indicated on the PCB.
	* When trying to get the initial placement it's best to start with opposing corners to ensure placement is correct.
*  Solder the Screen
	* Align the screen pins to match as shown in the location market DS1 on the PCB.
	* You can place the leftover breakaway header pins on the top side of the screen to help keep it level as you're soldering.
	* To ensure the fit solder the far pins first, its easier to refloat the solder in one pin than several.
*  Solder the Battery
	* Keep the solder iron away from the battery, high heat excites lithium in a violent manner.
	* When cutting the battery wires it is best practice to cut one wire at a time to avoid shorting anything and releasing the machine spirit.
	* Remove the film from the back of the battery stick and place the battery, wires toward the bottom, on the location marked with battery.
	* If the Micro PH/JST Connector is connected to the battery measure of the cable length you need to connect the wires to + and GND holes under the BT1 label.
	* Cut the connector off the battery, while ensuring you have enough wire on the connector left to make the connection for ESP32 board.
	* Double check the switch is in the "OFF" position 
	* Plug the PH/JST connector into the ESP32 board.  Note the polarity on the board with the positive connection being on the left.
		* Some of the PH/JST connectors in the kits have the wire colors flipped.  Insert the connector into the esp32 and check the reference photo above.  If the black wire is on the left side of the esp32, the black wire will be the + connection.
	* From the PH/JST connector solder the black wire into the GND socket next to the spot marked J1.
	* Solder the red wire from the connector into the + socket next to the spot marked J1.
	* Move back to the wires attached to the battery.
	* Solder the black wire into the GND socket under the spot marked BT1.
	* Solder the red wire into + socket
	
Set aside the bottom PCB and move to the top PCB.  Again except for the SAO connector the components will be on the side of the badge marked "-- Inside --"

*  Solder the 1x5 Female Headers
	* There are four locations for the Female Header
	* These go into the rectangles marked J#
* Solder the SAO connector
	* Flip the top PCB over
	* The 2x3 SAO connector goes into the 2x3 sockets on the top center of the badge.
	* Polarity matters for this.  The "wrong-way prevention bump" should be on the top, as indicated on the inside of the PCB.

## Additional Assembly Steps

Everything should be soldered onto the boards at this point.  
You will have extra male headers, but if there's anything else extra you may want to refer to the reference pictures above to figure out what went wrong.

* Attach PCBs
	* Align the female and male 1x5 headers from the top and bottom PCBs
	* Using a gentle but firm pressure press the two PCBs together.
	
* Power On
	* Flip the switch to on and catch them DeAuths.
	* NOTE: to charge the battery, the power switch must be set to the ON position.
	* Charge the battery by connection the USB-C connection on the ESP32 board to a power source.
	* Testing has indicated a full charge will last roughly seven hours, enough to look like a cool person for almost an entire work shift.	
	
* Attach Lanyard
	* Take one end of lanyard and put the clip in the clip hole.
	* Take the other end of the lanyard and put that one in the other clip hole.

Credits:
-- Badge Architect/Design: [@alt_bier](https://twitter.com/alt_bier) 
-- Badge Assembly/Design: DeCert
-- ESP23 Code: Emilia
-- Badge Assembly Instructions: Sh1tty

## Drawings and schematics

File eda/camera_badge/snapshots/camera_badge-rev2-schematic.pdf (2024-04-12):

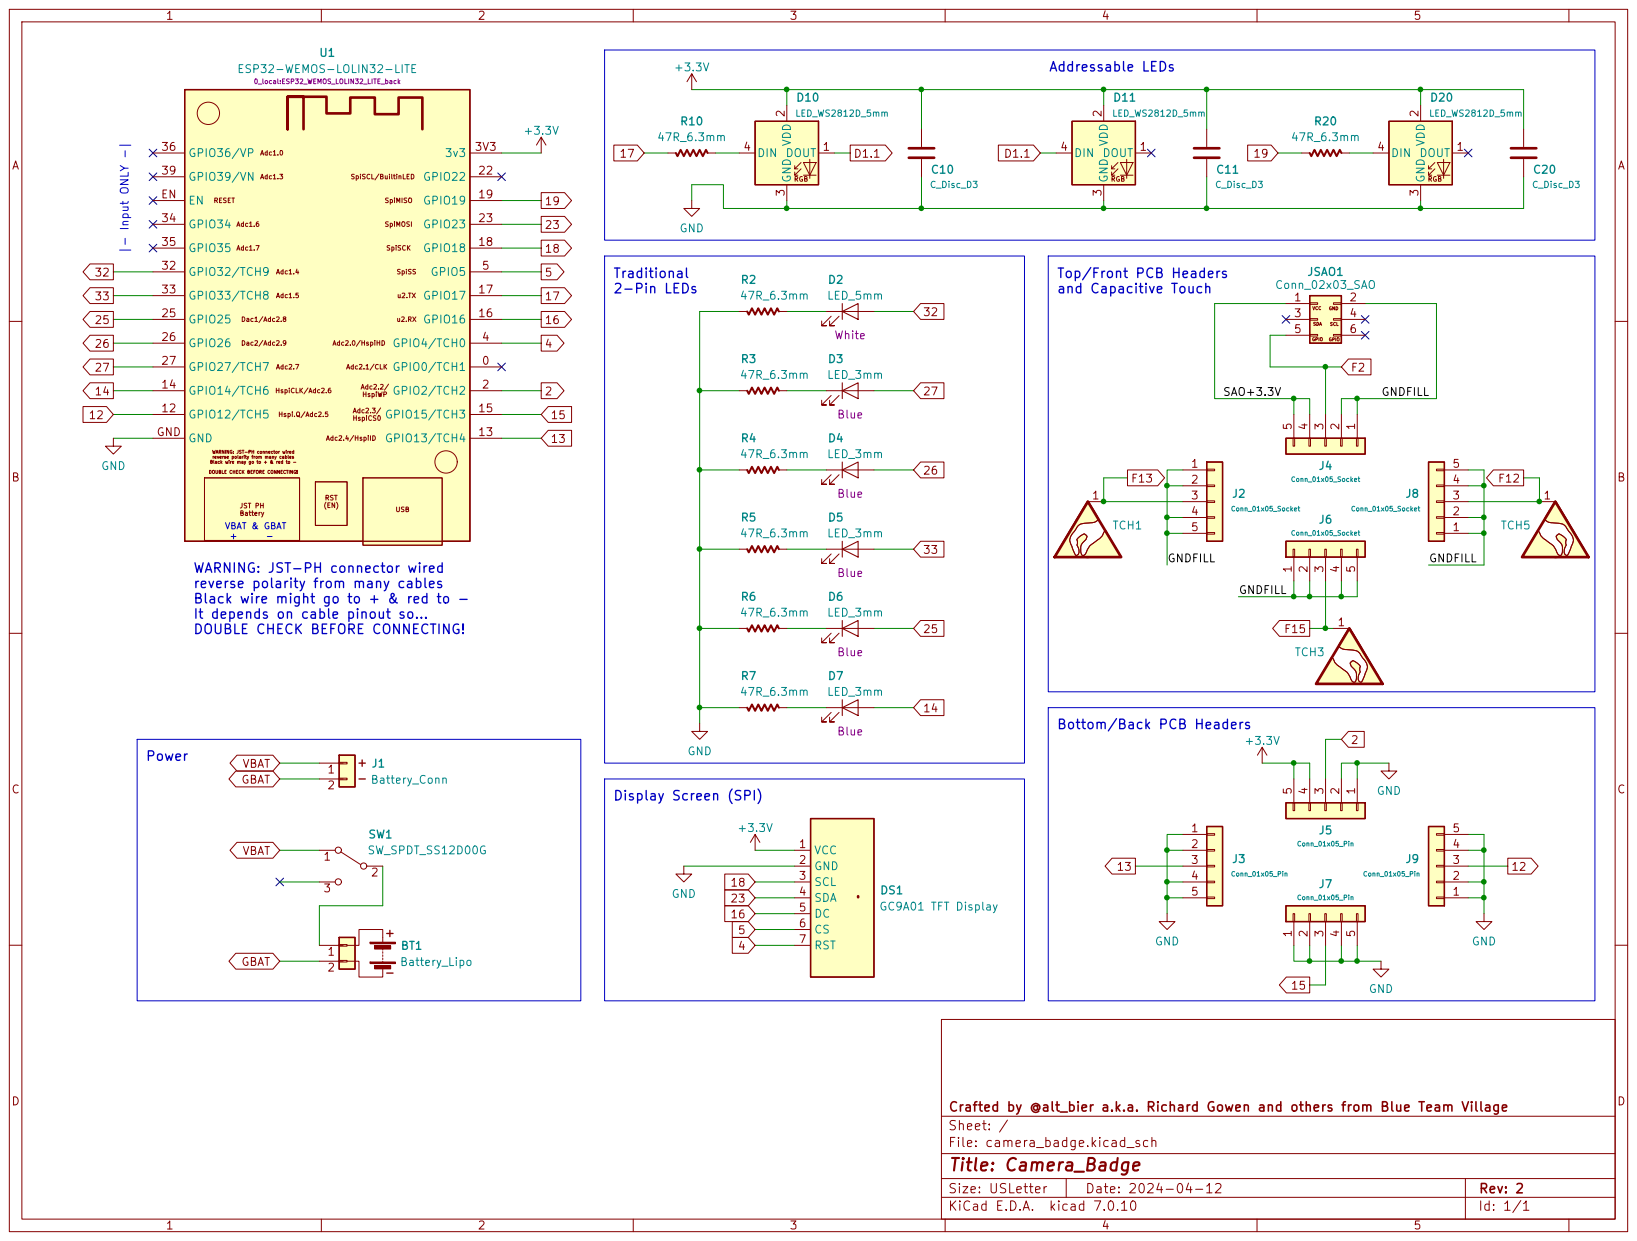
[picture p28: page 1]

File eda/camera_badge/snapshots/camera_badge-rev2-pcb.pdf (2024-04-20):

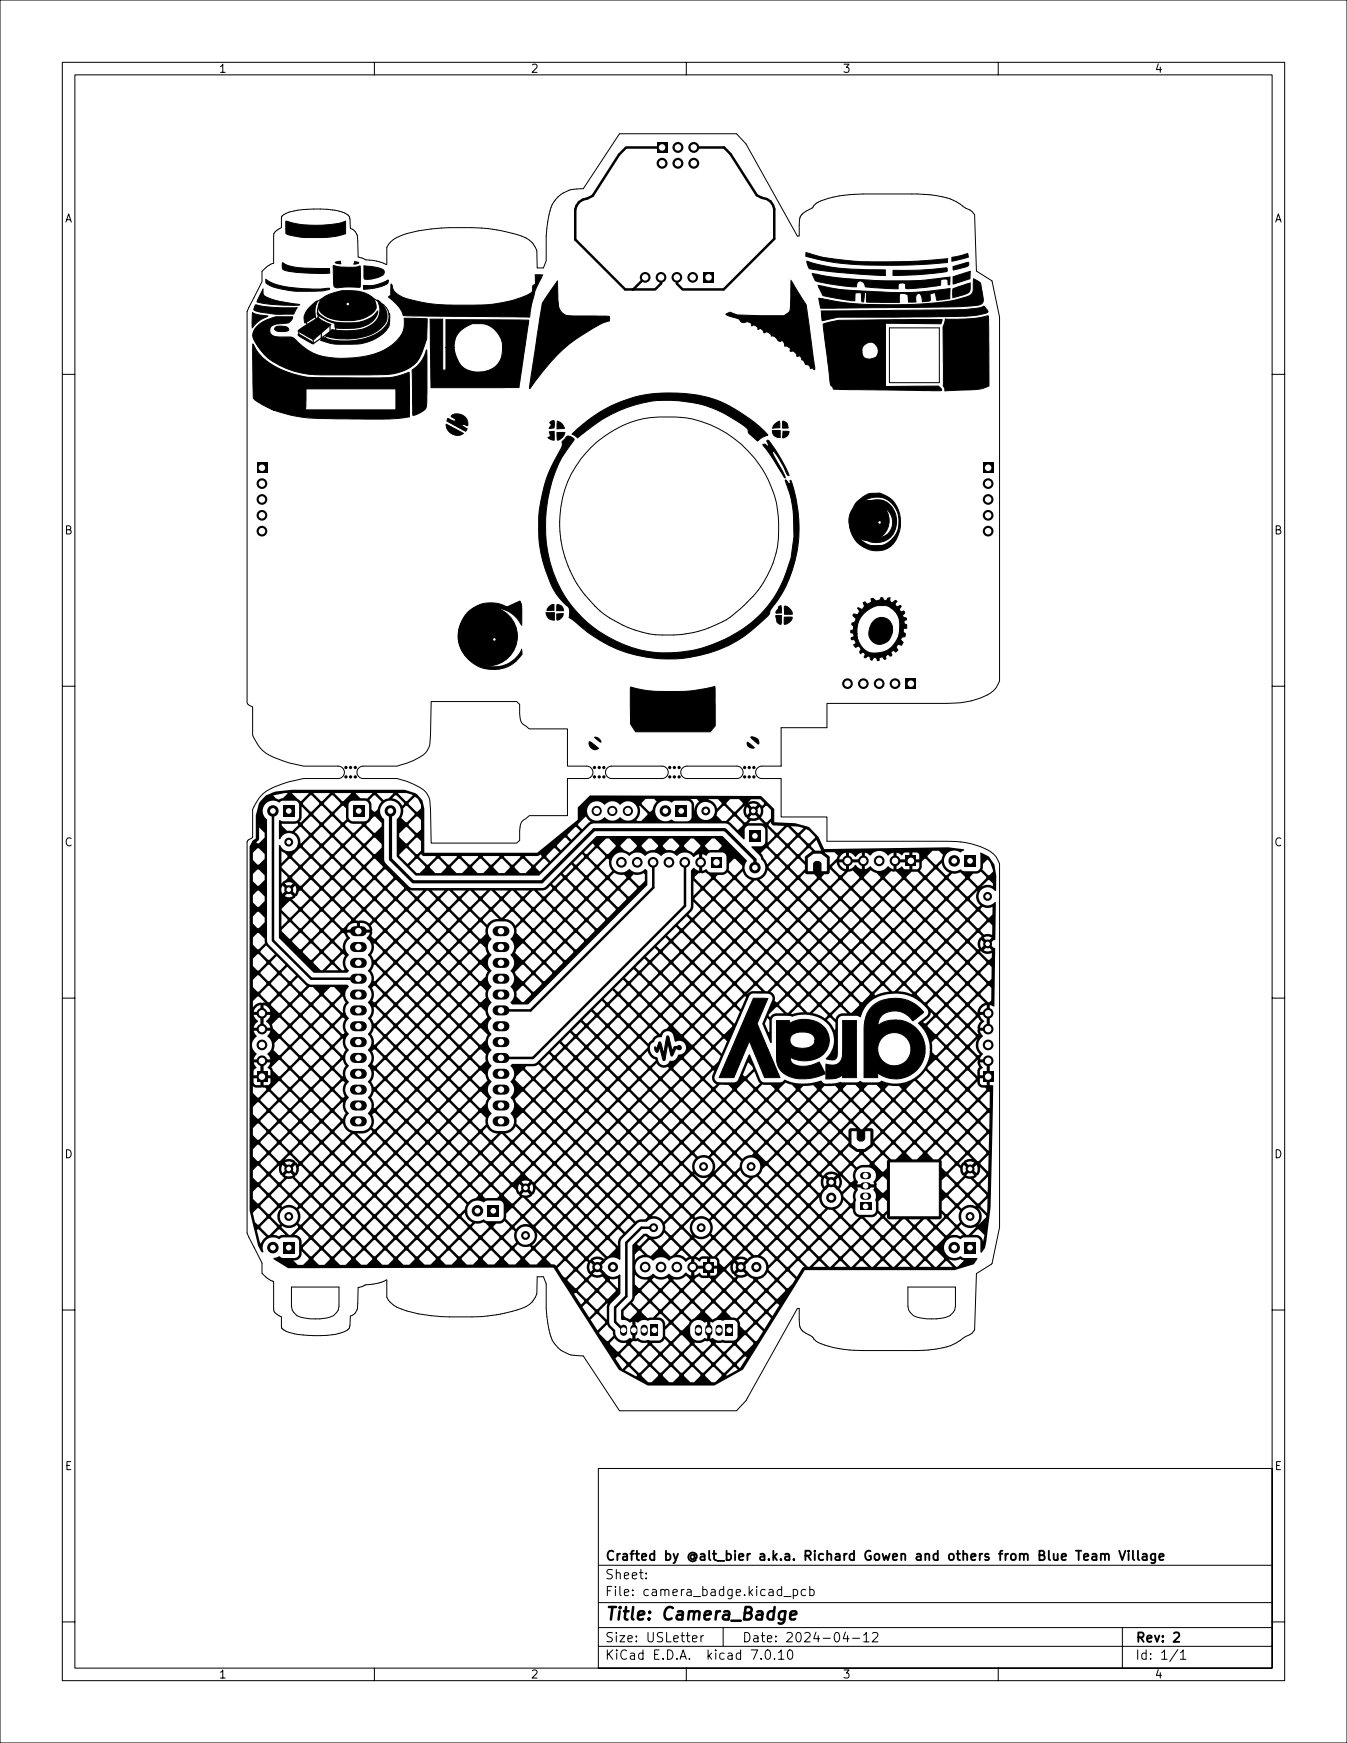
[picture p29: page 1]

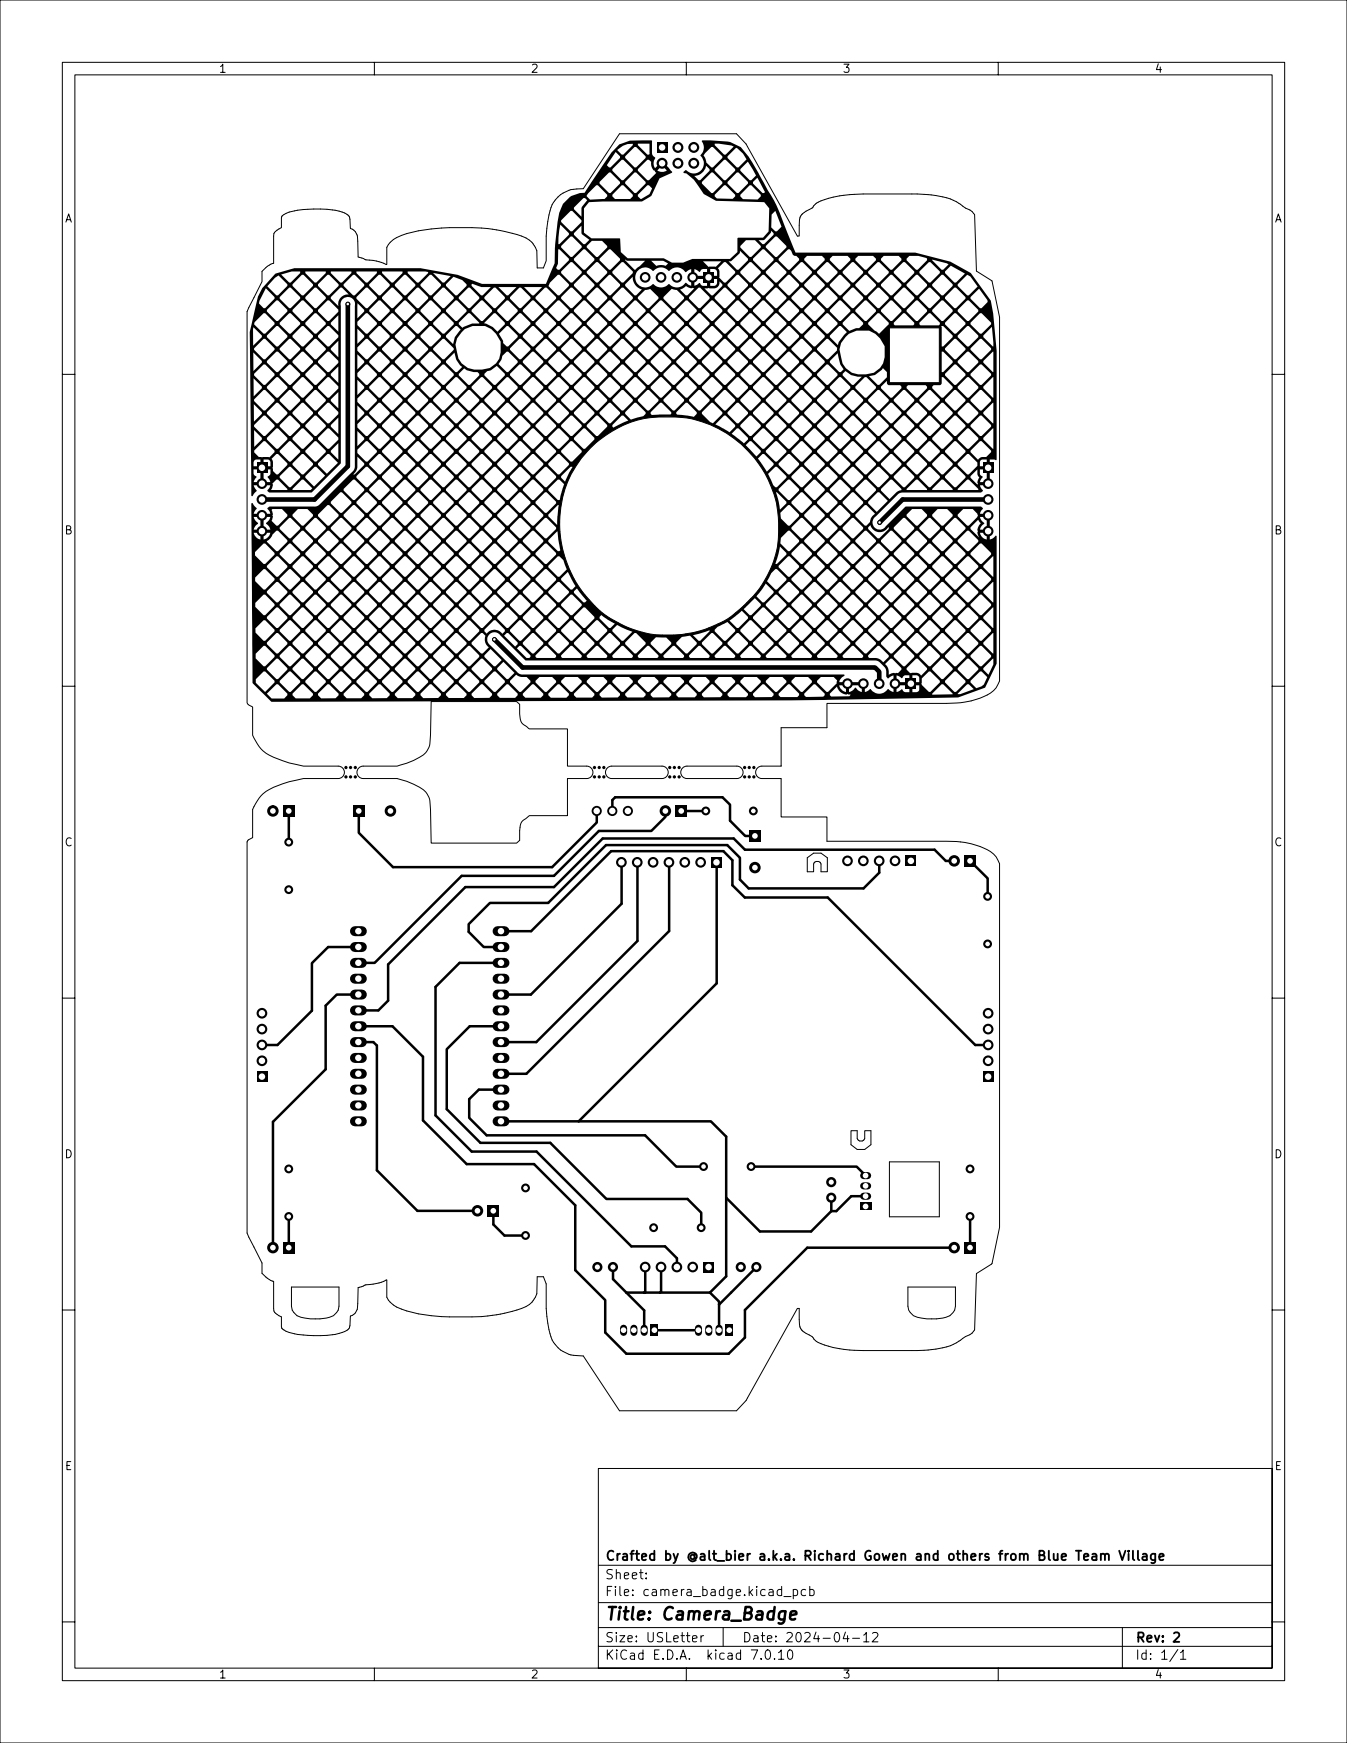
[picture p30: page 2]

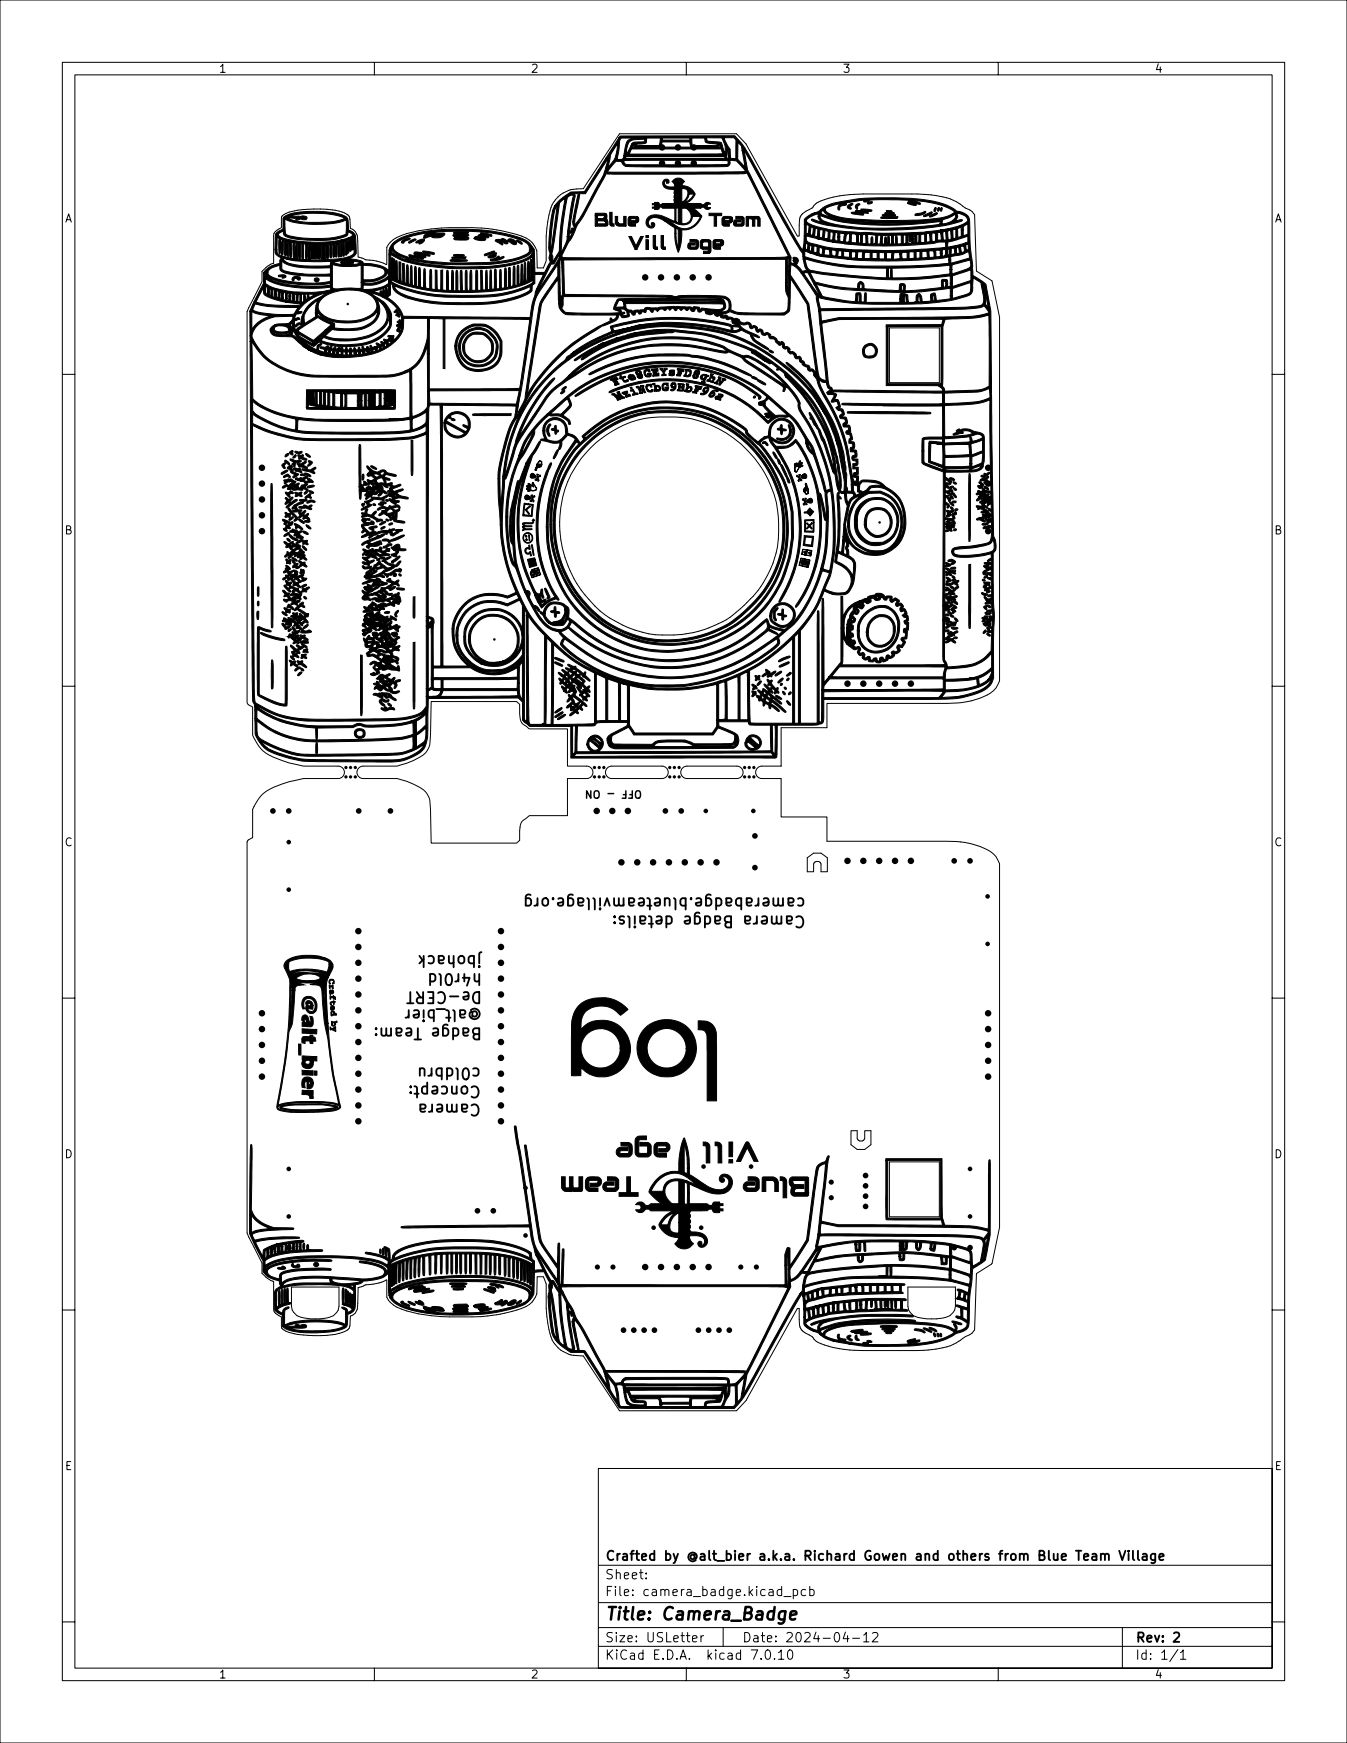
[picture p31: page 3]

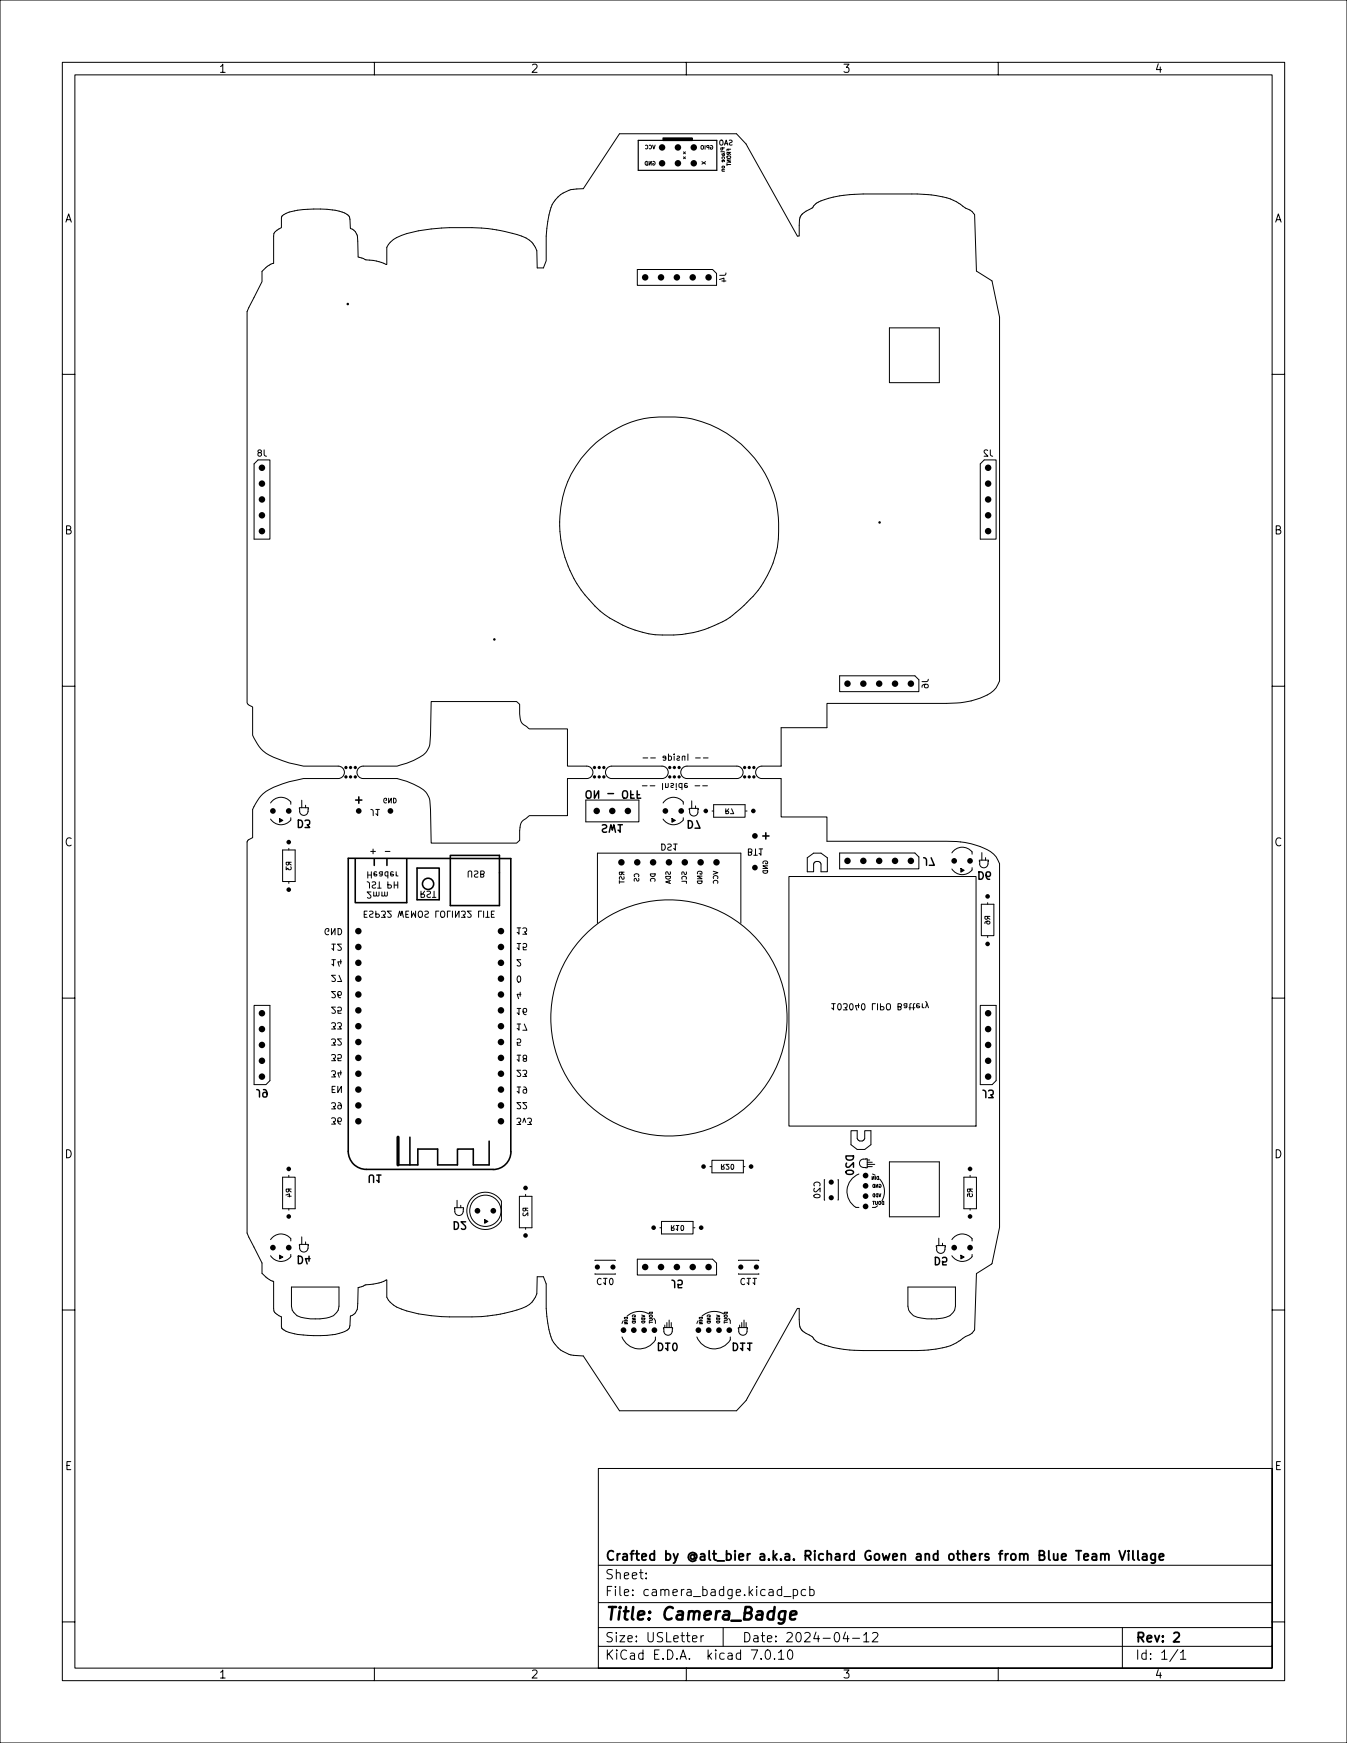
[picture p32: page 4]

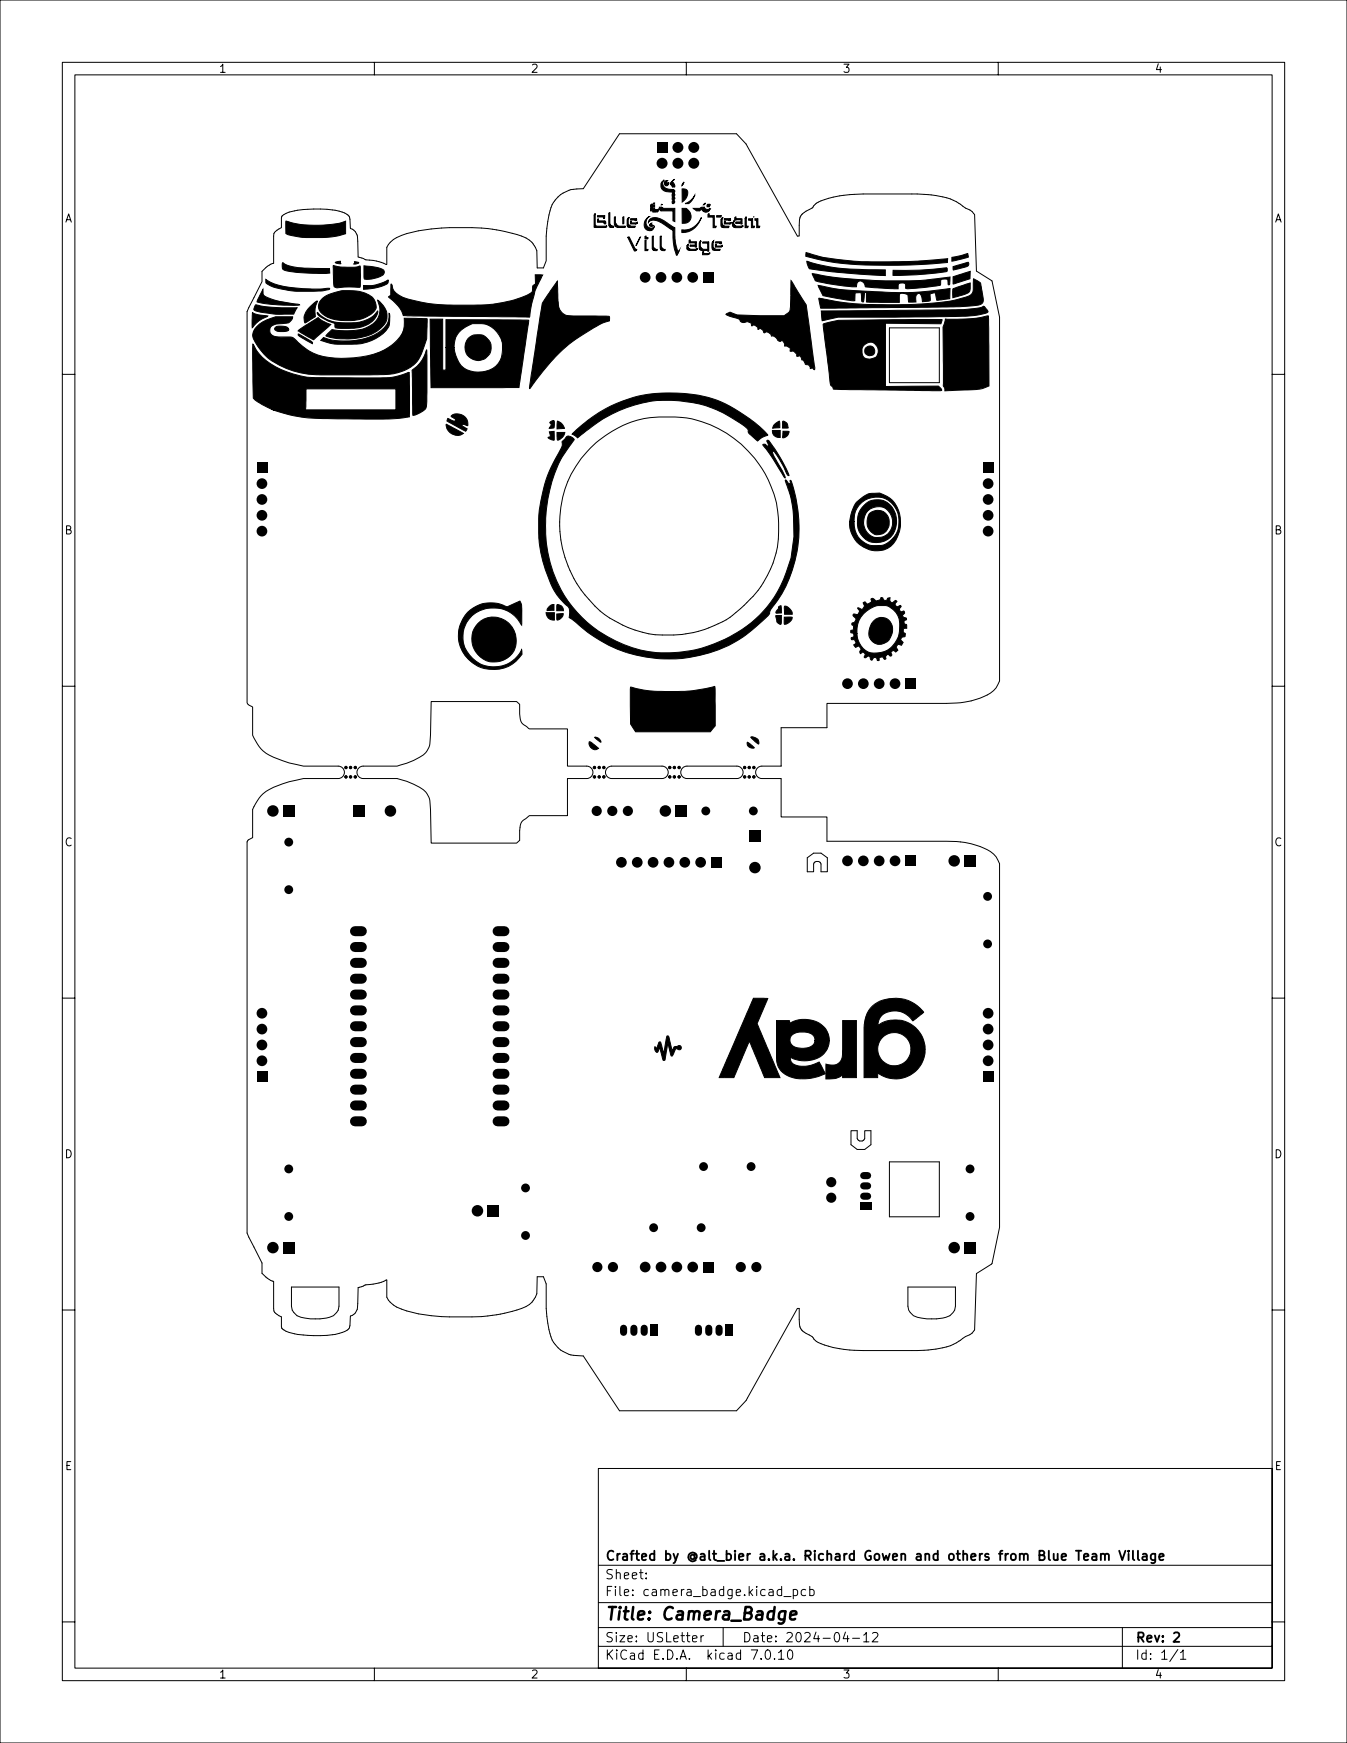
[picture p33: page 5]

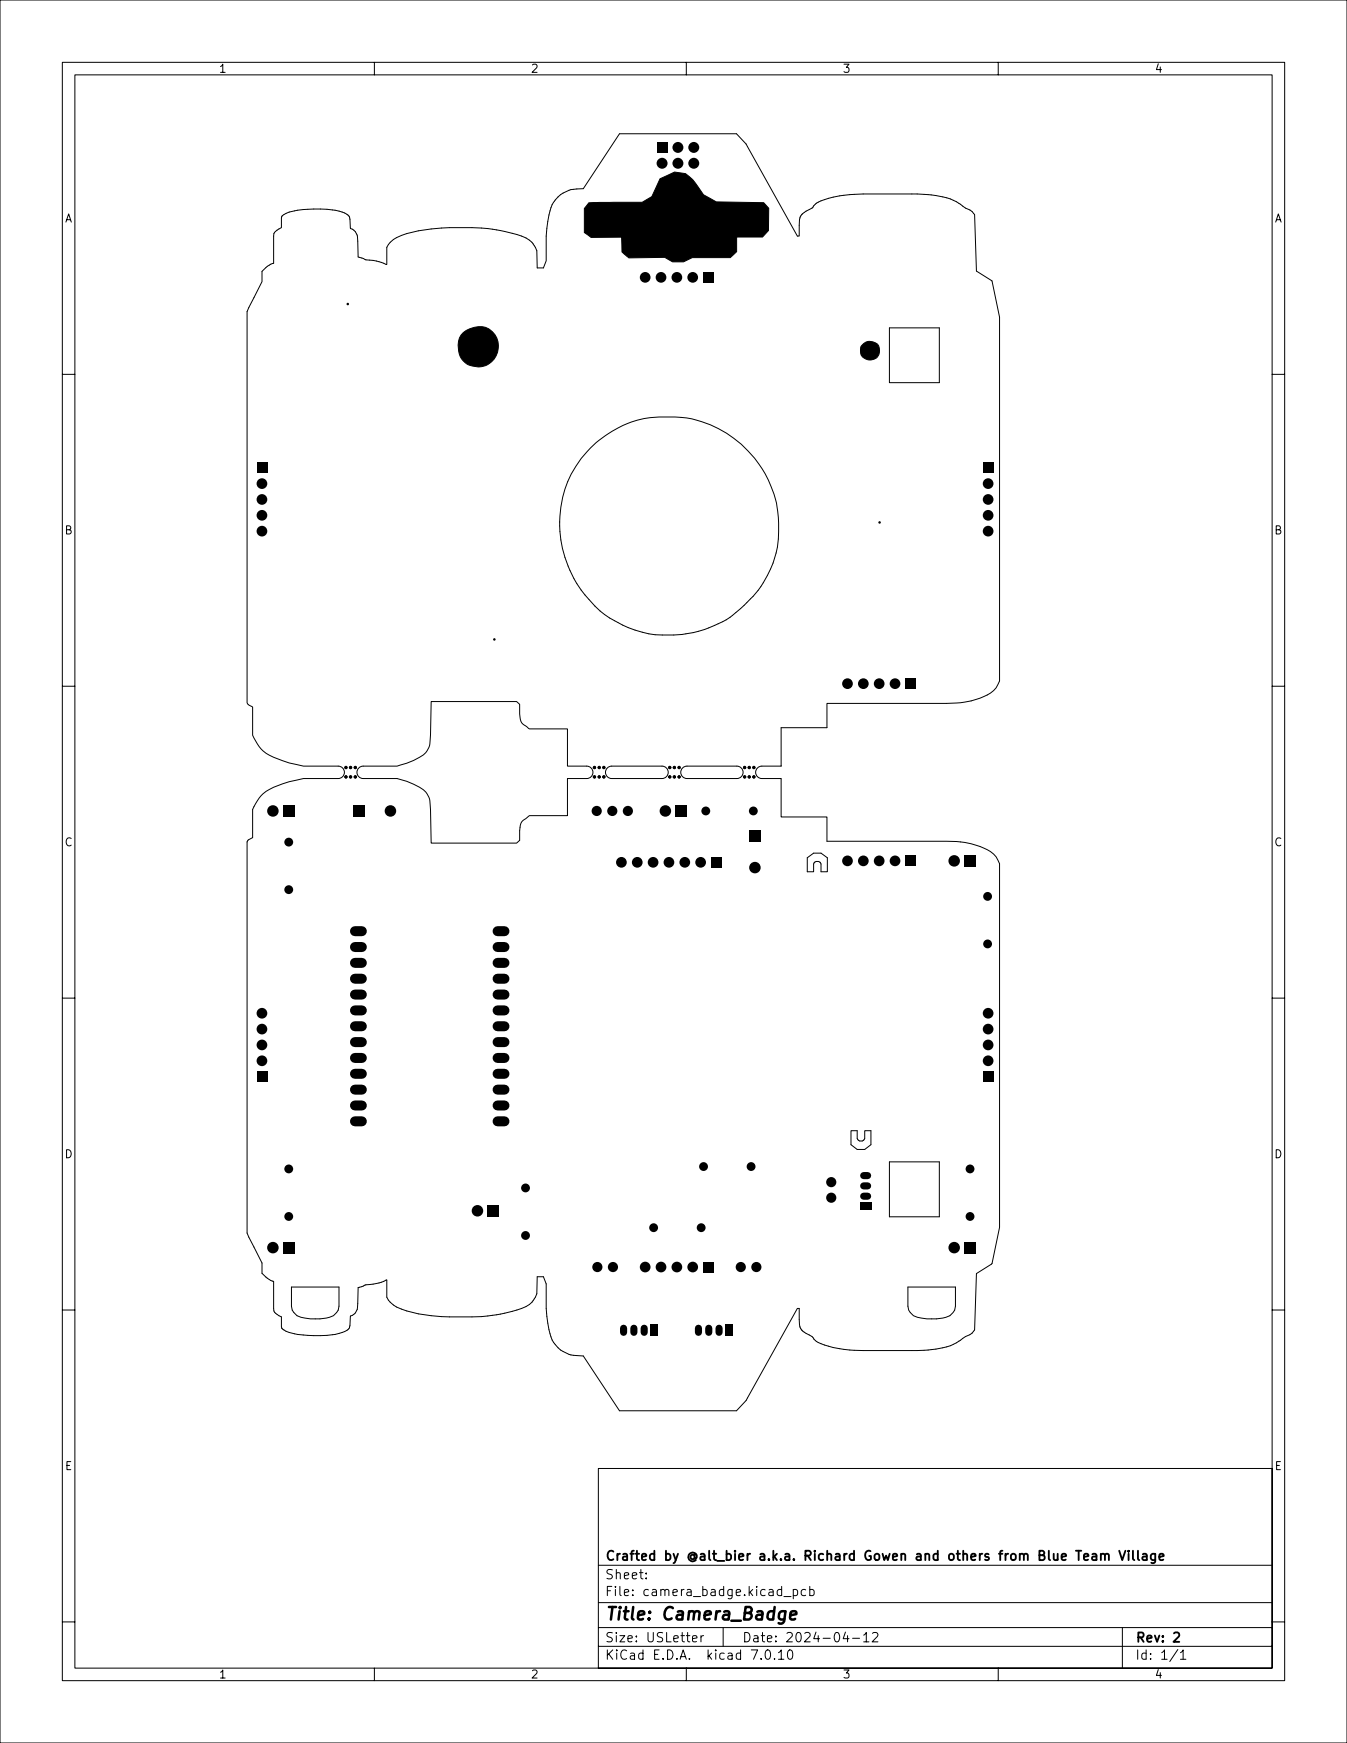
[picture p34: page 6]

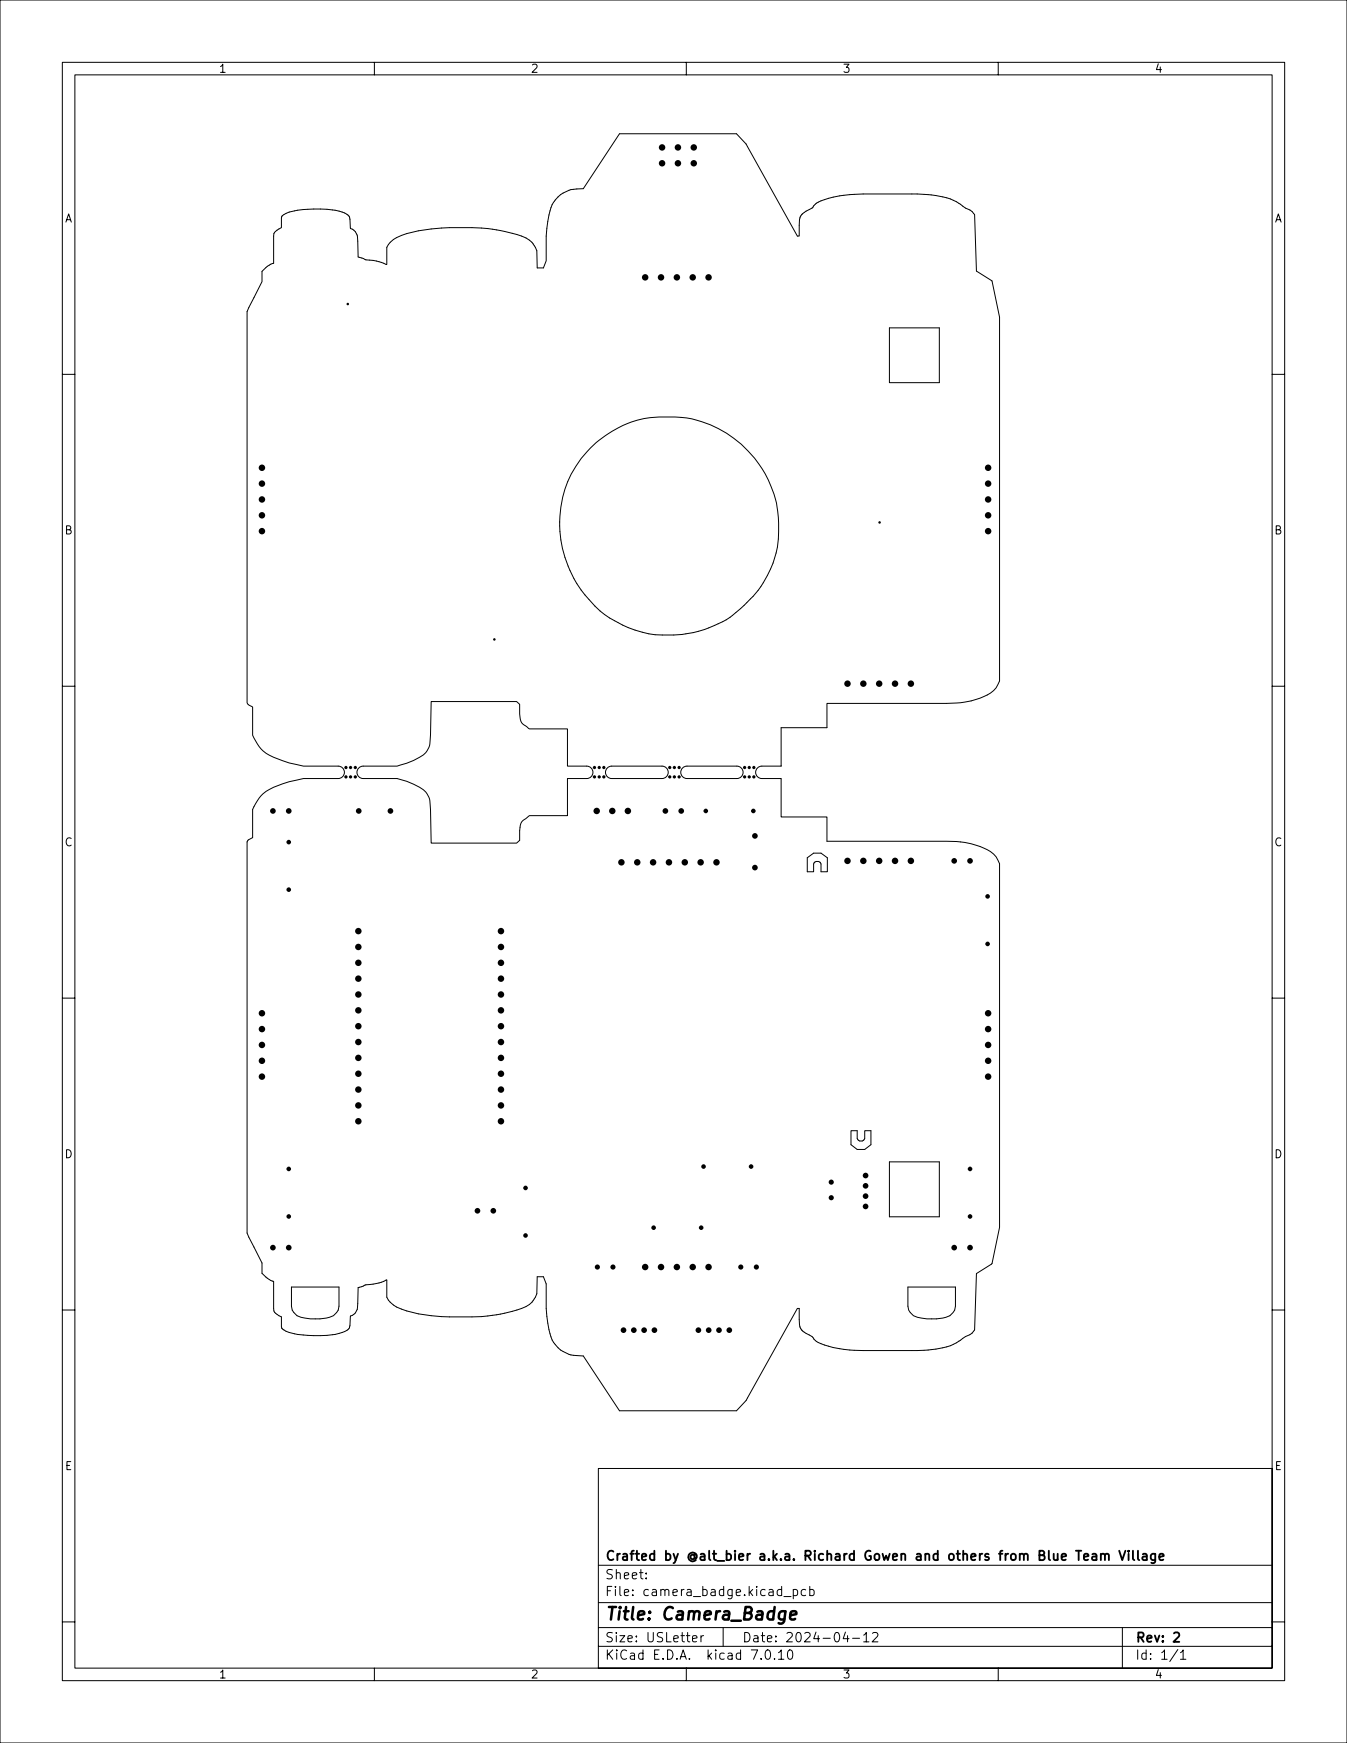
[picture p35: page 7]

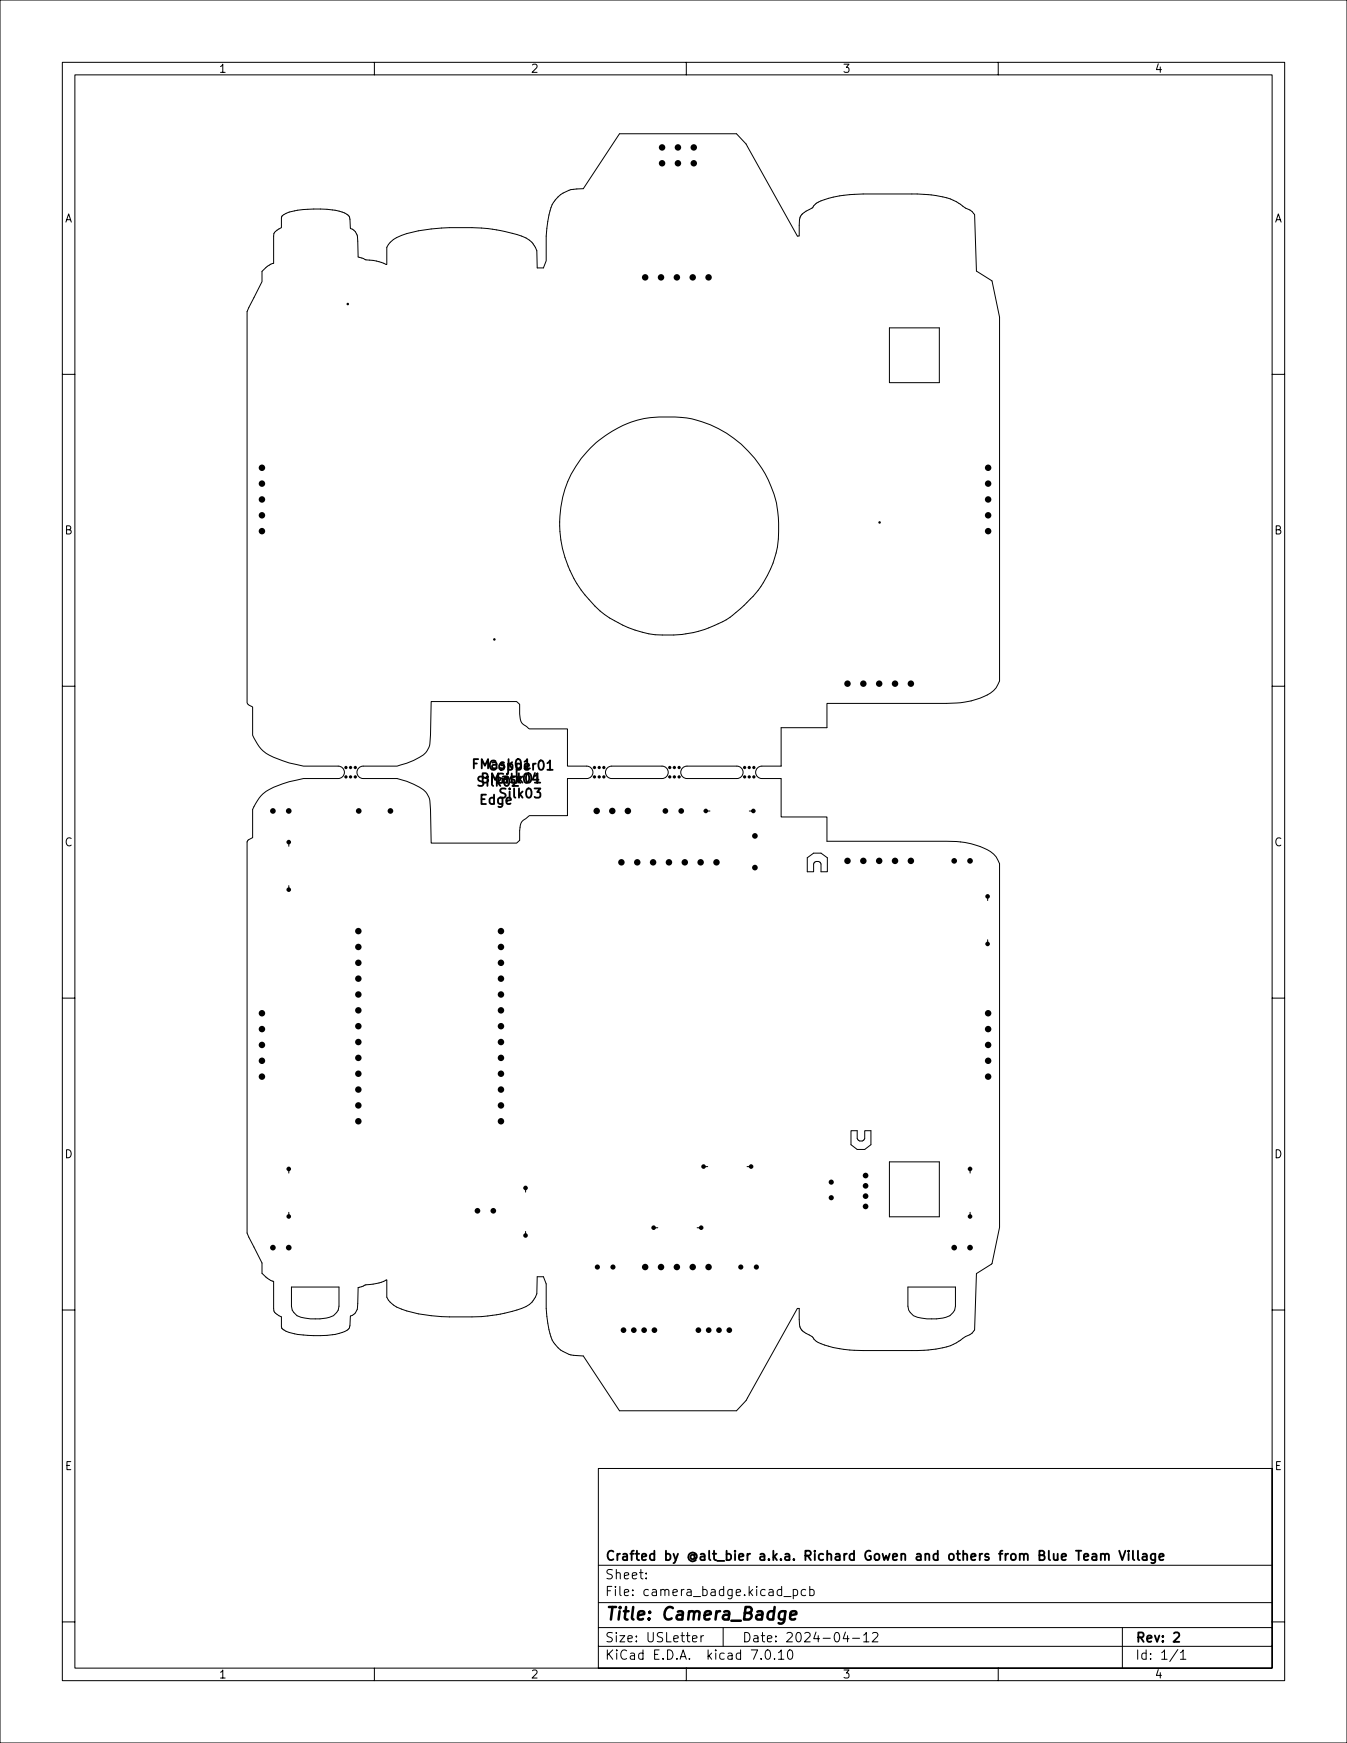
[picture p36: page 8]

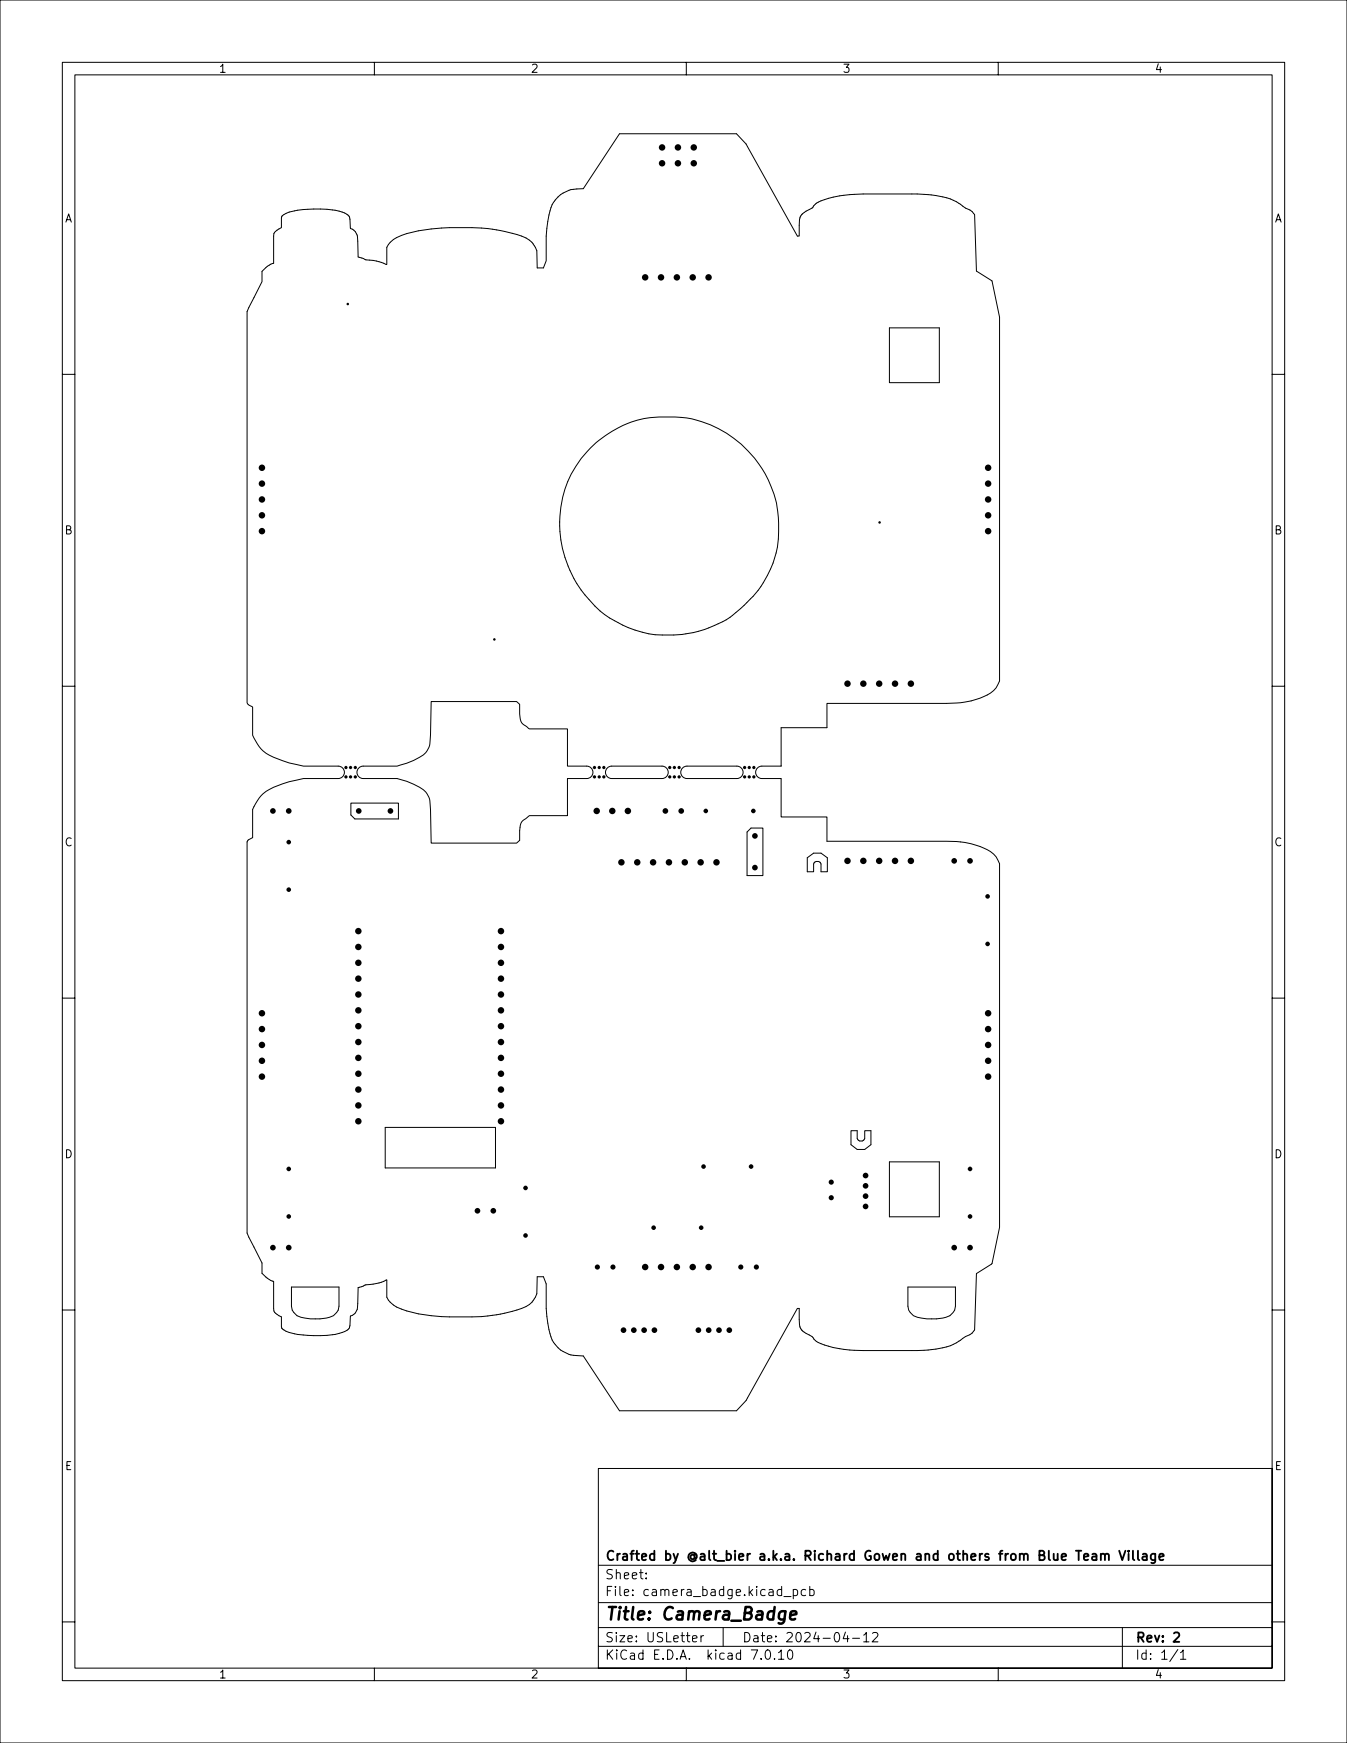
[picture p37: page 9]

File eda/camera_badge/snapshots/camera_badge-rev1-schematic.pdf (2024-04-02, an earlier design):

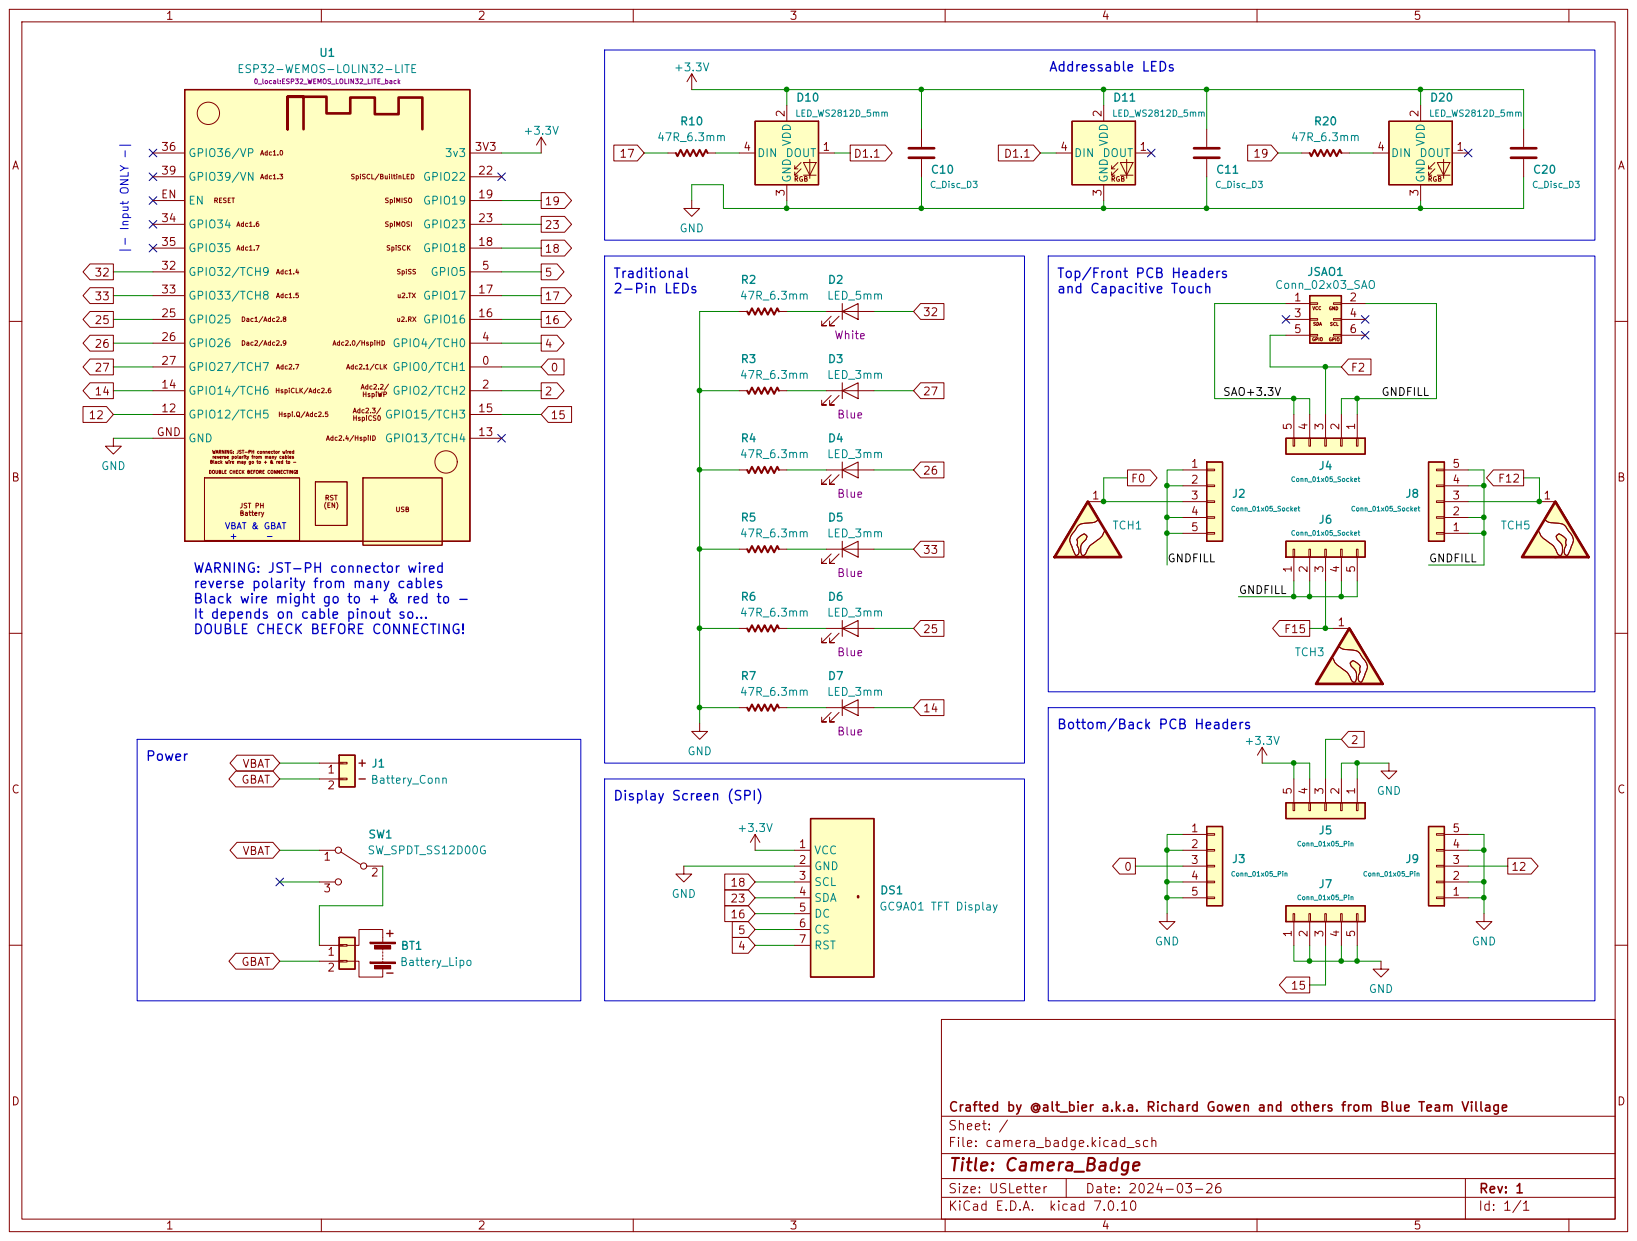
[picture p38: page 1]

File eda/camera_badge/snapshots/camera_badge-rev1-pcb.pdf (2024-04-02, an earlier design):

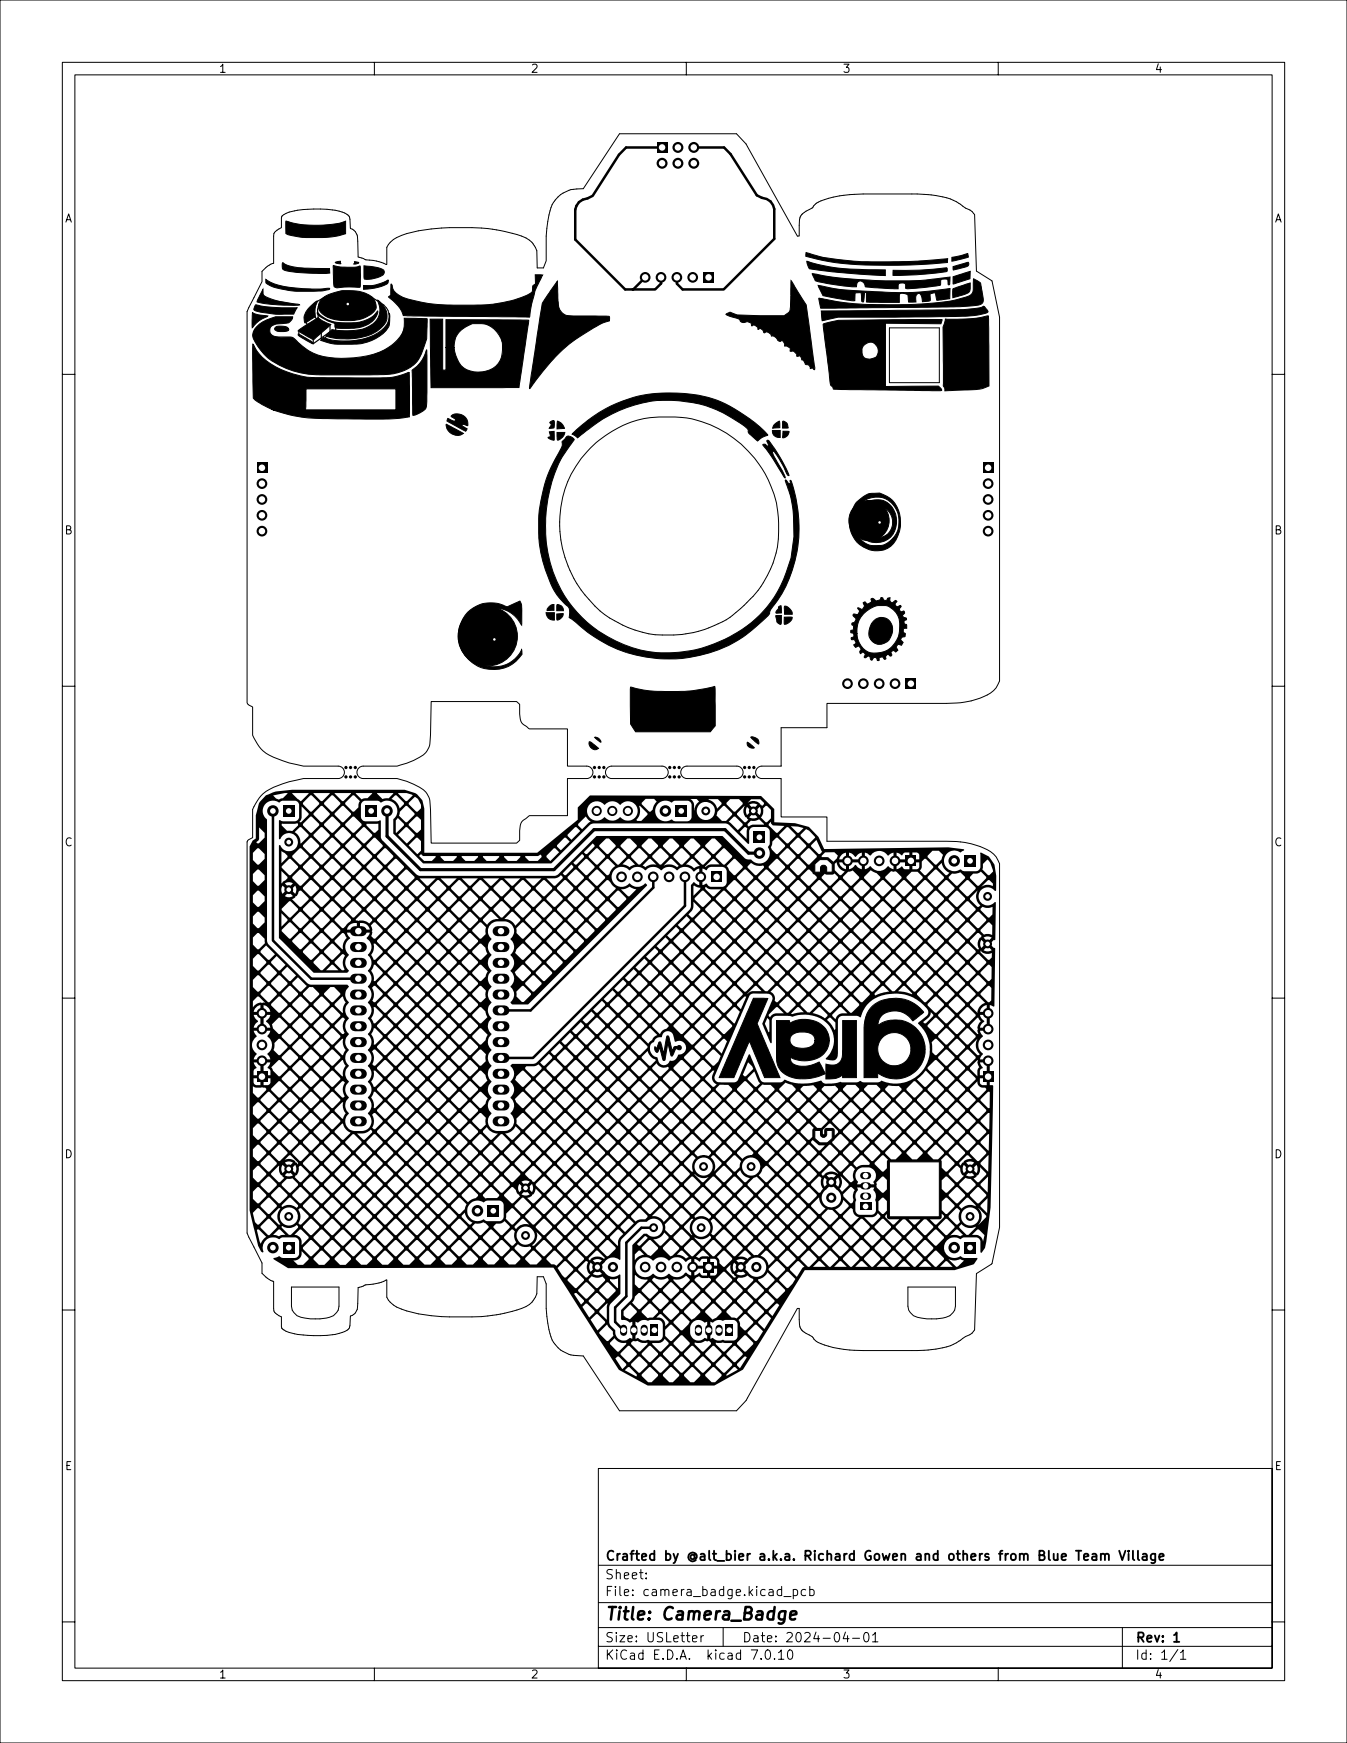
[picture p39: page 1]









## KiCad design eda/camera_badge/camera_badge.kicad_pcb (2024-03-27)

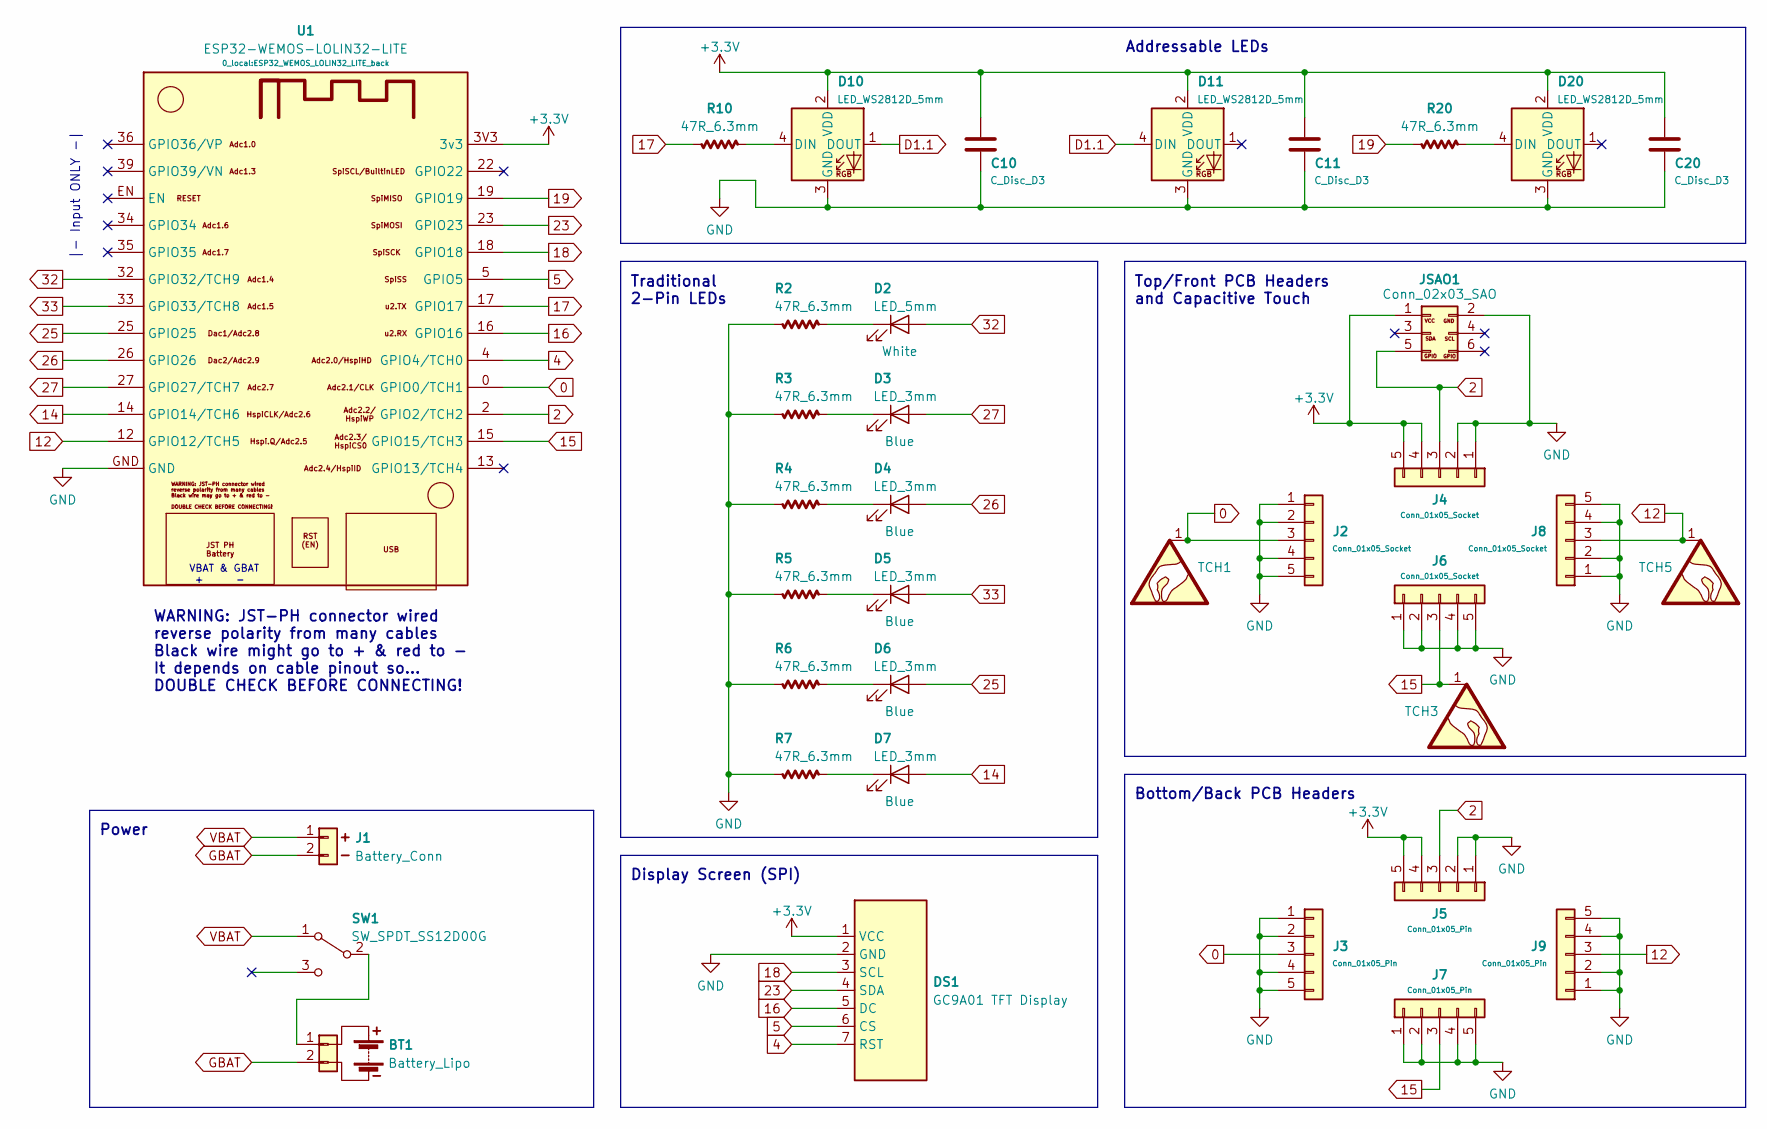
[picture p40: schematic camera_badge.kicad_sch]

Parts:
BT1: Battery_Lipo; Battery_Connector_back
C10, C11, C20: C_Disc_D3; C_Disc_D3_back
D2: LED_5mm; LED_D5.0mm-2_back
D3, D4, D5, D6, D7: LED_3mm; LED_D3.0mm-2-std_back
D10, D11, D20: LED_WS2812D_5mm; LED_D5.0mm-4_WS2812D_2024_back
DS1: GC9A01 TFT Display; GC9A01_TFT_Back_Mount
J1: Battery_Conn; Battery_Connector_back
J2, J4, J6, J8: Conn_01x05_Socket; Conn_Pin_Header_Female_Vert_Back_1x05_Pitch2.54mm
J3, J5, J7, J9: Conn_01x05_Pin; Conn_Pin_Header_Male_Vert_Back_1x05_Pitch2.54mm
JSAO1: Conn_02x03_SAO; SAOv169-BADGEv2-2x3_gpio_back
R2, R3, R4, R5, R6, R7, R10, R20: 47R_6.3mm; R_Axial_DIN0207_L6.3_D2.5_P7.62_Horiz_back
SW1: SW_SPDT_SS12D00G; SW_SPDT_Slide_SS12D00G-1P2T_3pin_back
TCH1, TCH3, TCH5: SYM_Touch_lg
U1: ESP32-WEMOS-LOLIN32-LITE; ESP32_WEMOS_LOLIN32_LITE_back

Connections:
0: J2.3, J3.3, TCH1.1, U1.0 (GPIO0/TCH1)
2: J4.3, J5.3, JSAO1.5, U1.2 (GPIO2/TCH2)
4: DS1.7 (RST), U1.4 (GPIO4/TCH0)
5: DS1.6 (CS), U1.5 (GPIO5)
12: J8.3, J9.3, TCH5.1, U1.12 (GPIO12/TCH5)
14: D7.2 (A), U1.14 (GPIO14/TCH6)
15: J6.3, J7.3, TCH3.1, U1.15 (GPIO15/TCH3)
16: DS1.5 (DC), U1.16 (GPIO16)
17: R10.2, U1.17 (GPIO17)
18: DS1.3 (SCL), U1.18 (GPIO18)
19: R20.2, U1.19 (GPIO19)
23: DS1.4 (SDA), U1.23 (GPIO23)
25: D6.2 (A), U1.25 (GPIO25)
26: D4.2 (A), U1.26 (GPIO26)
27: D3.2 (A), U1.27 (GPIO27/TCH7)
32: D2.2 (A), U1.32 (GPIO32/TCH9)
33: D5.2 (A), U1.33 (GPIO33/TCH8)
+3.3V: C10.1, C11.1, C20.1, D10.2 (VDD), D11.2 (VDD), D20.2 (VDD), DS1.1 (VCC), J4.4, J4.5, J5.4, J5.5, JSAO1.1, U1.3V3 (3v3)
D1.1: D10.1 (DOUT), D11.4 (DIN)
GBAT: BT1.2, J1.2
GND: C10.2, C11.2, C20.2, D10.3 (GND), D11.3 (GND), D20.3 (GND), DS1.2 (GND), J2.1, J2.2, J2.4, J2.5, J3.1, J3.2, J3.4, J3.5, J4.1, J4.2, J5.1, J5.2, J6.1, J6.2, J6.4, J6.5, J7.1, J7.2, J7.4, J7.5, J8.1, J8.2, J8.4, J8.5, J9.1, J9.2, J9.4, J9.5, JSAO1.2, R2.2, R3.2, R4.2, R5.2, R6.2, R7.2, U1.GND
unnamed: BT1.1, SW1.2 (B)
unnamed: D2.1 (K), R2.1
unnamed: D3.1 (K), R3.1
unnamed: D4.1 (K), R4.1
unnamed: D5.1 (K), R5.1
unnamed: D6.1 (K), R6.1
unnamed: D7.1 (K), R7.1
unnamed: D10.4 (DIN), R10.1
unnamed: D20.4 (DIN), R20.1
VBAT: J1.1, SW1.1 (A)

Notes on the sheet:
Power
WARNING: JST-PH connector wired reverse polarity from many cables Black wire might go to + & red to - It depends on cable pinout so... DOUBLE CHECK BEFORE CONNECTING!
Display Screen (SPI)
|- Input ONLY -|
Top/Front PCB Headers and Capacitive Touch
VBAT & GBAT + -
Traditional 2-Pin LEDs
Bottom/Back PCB Headers
Addressable LEDs

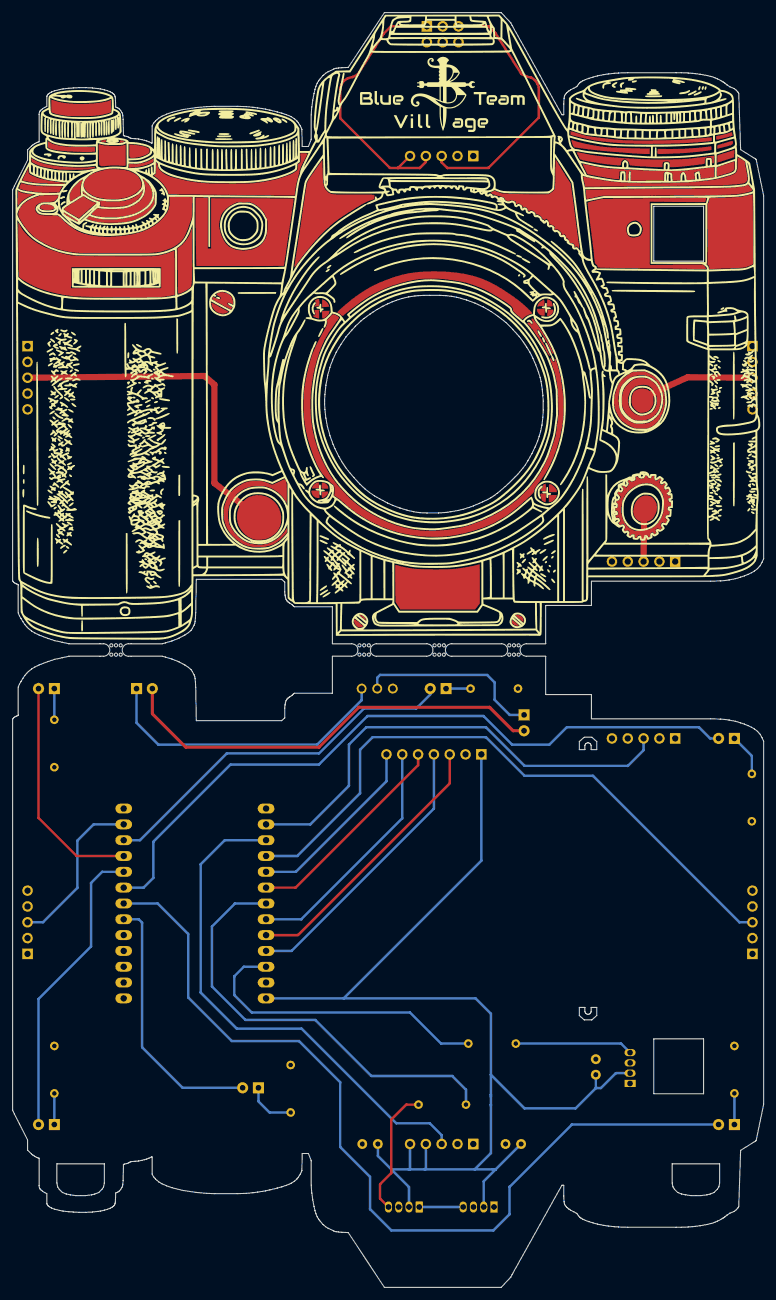
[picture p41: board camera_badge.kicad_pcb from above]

Board: 2 copper layers, 120.6 x 204.7 mm, 44 parts (0 on the bottom side), 31 nets.

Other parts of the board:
Band_Fastener: Band_Fastener_Hook
Band_Fastener#2: Band_Fastener_Hook
LIPO: Battery_LIPO_103040_silk_back
Lanyard: Lanyard_Hole
Lanyard#2: Lanyard_Hole
badge_bmask01: BMask01; camera_badge_bmask01
badge_copper01: Copper01; camera_badge_copper01
badge_edgecuts: Edge; camera_badge_edgecuts
badge_fmask01: FMask01; camera_badge_fmask01
badge_silk02: Silk02; camera_badge_silk02

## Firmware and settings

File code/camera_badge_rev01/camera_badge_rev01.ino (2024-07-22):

// camera_badge_rev01

// Include Libraries
#include <Arduino.h>
#include <WiFi.h>
#include "Adafruit_NeoPixel.h"
#include "SPI.h"
#include "Adafruit_GFX.h"
#include "Adafruit_GC9A01A.h"
#include <esp_wifi_types.h>
#include <esp_wifi.h>
#include <BLEDevice.h>
#include <BLEUtils.h>
#include <BLEScan.h>
#include <BLEAdvertisedDevice.h>

// Pin Definitions
//
// Display Pins
#define TFT_DC 16
#define TFT_CS 5
#define TFT_RST 4
// Note: SPI DATA & CLOCK defined by pins_arduino.h in ESP32 Board Library
// SPI data pin = MOSI 23
// SPI clock pin = SCK 18
//
// NeoPixel Data Pins
#define NEO01_DATA 17
#define NEO02_DATA 19
//
// One color LED Pins
#define LED_D2 32
#define LED_D3 27
#define LED_D4 26
#define LED_D5 33
#define LED_D6 25
#define LED_D7 14
//
// Built-in LED
#define LED_BI 22
//
// Capacitive Touch Pins
#define TCH01_PIN 13
#define TCH03_PIN 15
#define TCH05_PIN 12

// Display Properties
//
// Display constructor for primary hardware SPI connection
Adafruit_GC9A01A tft(TFT_CS, TFT_DC);

// NeoPixel Properties
//
// Define NeoPixel Strips - (Num pixels, pin to send signals, pixel type, signal rate)
Adafruit_NeoPixel NEO01 = Adafruit_NeoPixel(2, NEO01_DATA, NEO_RGB + NEO_KHZ800);
Adafruit_NeoPixel NEO02 = Adafruit_NeoPixel(1, NEO02_DATA, NEO_RGB + NEO_KHZ800);
// Status NeoPixel LED color mode bitwise off=0 red=1 green=2 blue=4
int status_neo_mode = 0;

// PWM Properties
//
// Signal Frequency in Hz
const int freq = 1000;
// Duty Cycle Resolution in bits (1-16)
const int resolution = 8;
// PWM channel Assignment (0-15)
const int LED_D3_pwm = 3;
const int LED_D4_pwm = 4;
const int LED_D5_pwm = 5;
const int LED_D6_pwm = 6;
const int LED_D7_pwm = 7;

// Wireless Properties
//
// WIFI status codes
const char *wl_status_to_string(wl_status_t status)
{
  switch (status)
  {
  case WL_NO_SHIELD:
    return "WL_NO_SHIELD";
  case WL_IDLE_STATUS:
    return "WL_IDLE_STATUS";
  case WL_NO_SSID_AVAIL:
    return "WL_NO_SSID_AVAIL";
  case WL_SCAN_COMPLETED:
    return "WL_SCAN_COMPLETED";
  case WL_CONNECTED:
    return "WL_CONNECTED";
  case WL_CONNECT_FAILED:
    return "WL_CONNECT_FAILED";
  case WL_CONNECTION_LOST:
    return "WL_CONNECTION_LOST";
  case WL_DISCONNECTED:
    return "WL_DISCONNECTED";
  }
}

//
// DEAUTH SNIFF Properties
#define MAX_CHANNELS 13
const unsigned long CHANNEL_HOP_INTERVAL = 2500;
unsigned long previousChannelHopTime = 0;
const wifi_promiscuous_filter_t filt = {.filter_mask = WIFI_PROMIS_FILTER_MASK_MGMT | WIFI_PROMIS_FILTER_MASK_DATA};
int currentChannel = 1;
unsigned long deauthThreshold = 20;
unsigned long deauthCount = 0;
typedef struct
{
  int16_t fctl;
  int16_t duration;
  uint8_t da;
  uint8_t sa;
  uint8_t bssid;
  int16_t seqctl;
  unsigned char payload[];
} WifiMgmtHdr;
typedef struct
{
  unsigned frame_ctrl : 16;
  unsigned duration_id : 16;
  uint8_t addr1[6]; /* receiver address */
  uint8_t addr2[6]; /* sender address */
  uint8_t addr3[6]; /* filtering address */
  unsigned sequence_ctrl : 16;
  uint8_t addr4[6]; /* optional */
} wifi_ieee80211_mac_hdr_t;
typedef struct
{
  uint8_t payload[0];
  wifi_ieee80211_mac_hdr_t hdr;
} wifi_ieee80211_packet_t_2;
typedef struct
{
  uint8_t payload[0];
  WifiMgmtHdr hdr;
} wifi_ieee80211_packet_t;
bool deauth_sniff_active = false;

//
// BLE Properties
const int SCAN_TIME = 5; // scan duration in seconds
const String FLIPPER_MAC_PREFIX_1 = "80:e1:26";
const String FLIPPER_MAC_PREFIX_2 = "80:e1:27";
BLEScan *pBLEScan;
int flipperCount = 0;
bool flipper_scan_active = false;

class MyAdvertisedDeviceCallbacks : public BLEAdvertisedDeviceCallbacks
{
  void onResult(BLEAdvertisedDevice advertisedDevice)
  {
    String macAddress = String(advertisedDevice.getAddress().toString().c_str());
    if (macAddress.startsWith(FLIPPER_MAC_PREFIX_1) || macAddress.startsWith(FLIPPER_MAC_PREFIX_2))
    {
      flipperCount++;
    }
  }
};
//

// Capacitive Touch Properties
//
// Touch Thresholds
int Touch01_Threshold = 19;
int Touch03_Threshold = 19;
int Touch05_Threshold = 19;
// Touch Initial Values
int Touch01_Value = 21;
int Touch03_Value = 21;
int Touch05_Value = 21;
//
// Touch Counters
//
// Touch Iteration Counter
int Touch01_IntCount = 0;
int Touch03_IntCount = 0;
int Touch05_IntCount = 0;
// Touch Iteration Flag
int Touch01_IntFlag = 0;
int Touch03_IntFlag = 0;
int Touch05_IntFlag = 0;
// Touch Loop Counter
int Touch01_LoopCount = 0;
int Touch03_LoopCount = 0;
int Touch05_LoopCount = 0;
// Touch Loop Threshold (Touch Held for X Loops of Main)
int Touch01_Loop_Threshold = 3;
int Touch03_Loop_Threshold = 3;
int Touch05_Loop_Threshold = 3;

// Loop Control Properties
//
// Main Loop LED Iteration Delay Time [in ms]
int LEDDelayTime = 20;
//
// Debug Serial - If set greater than 0 it writes to serial for debugging
// 0 = no debug text
// 1 = basic debug info once per main loop
// 2 = extra debug info
int DebugSerial = 2;

// //////////////////////////////////////////////////
//
// SETUP - RUN ONCE
//
// //////////////////////////////////////////////////
void setup()
{
  // Add a delay to allow opening serial monitor
  delay(800);

  // setup the serial output baud rate
  Serial.begin(115200);

  if (DebugSerial >= 1)
  {
    Serial.println("Starting Setup");
  }

  // Turn Off WiFi/BT
  if (DebugSerial >= 2)
  {
    Serial.println("Turn Off WiFi / BlueTooth");
  }
  setModemSleep();

  // Configure LED PWM functionalitites per channel
  if (DebugSerial >= 2)
  {
    Serial.println("Configure PWM Channels");
  }
  ledcSetup(LED_D3_pwm, freq, resolution);
  ledcSetup(LED_D4_pwm, freq, resolution);
  ledcSetup(LED_D5_pwm, freq, resolution);
  ledcSetup(LED_D6_pwm, freq, resolution);
  ledcSetup(LED_D7_pwm, freq, resolution);

  // Attach the channel to the GPIO to be controlled
  if (DebugSerial >= 2)
  {
    Serial.println("Attach PWM Channels to LED Pins");
  }
  ledcAttachPin(LED_D3, LED_D3_pwm);
  ledcAttachPin(LED_D4, LED_D4_pwm);
  ledcAttachPin(LED_D5, LED_D5_pwm);
  ledcAttachPin(LED_D6, LED_D6_pwm);
  ledcAttachPin(LED_D7, LED_D7_pwm);

  // Normal LED output
  if (DebugSerial >= 2)
  {
    Serial.println("Set Output for non-PWM LED Pins");
  }
  pinMode(LED_D2, OUTPUT);
  pinMode(LED_BI, OUTPUT);

  // Initialize the NeoPixels
  if (DebugSerial >= 2)
  {
    Serial.println("Initialize NeoPixels");
  }
  NEO01.begin();
  NEO02.begin();
  // Set Neopixel Brightness (0-255 scale)
  NEO01.setBrightness(170);
  NEO02.setBrightness(170);

  // Initialize the Display
  if (DebugSerial >= 2)
  {
    Serial.println("Initialize Display");
  }
  tft.begin();

  // Start all LEDs in OFF mode
  if (DebugSerial >= 2)
  {
    Serial.println("Turn OFF all LEDs");
  }
  ledAllOff();

  //
  // Random Seed based on Touch03_Value
  randomSeed(touchRead(TCH03_PIN));

  if (DebugSerial >= 1)
  {
    Serial.println(F("Setup Done!"));
  }

  // END OF SETUP
}

// //////////////////////////////////////////////////
//
// LOOP - MAIN
//
// //////////////////////////////////////////////////
void loop()
{
  if (DebugSerial >= 1)
  {
    Serial.println("******************** TOP OF MAIN LOOP ********************");
  }
  // Capacitive Touch Dynamic Threshold Adjustment
  // Adjust thresholds UP to account for assembly conditions and battery vs usb
  Touch01_Value = touchRead(TCH01_PIN);
  if ((Touch01_Value / Touch01_Threshold) > 2)
  {
    Touch01_Threshold = int(Touch01_Threshold * 1.8);
  }
  Touch03_Value = touchRead(TCH03_PIN);
  if ((Touch03_Value / Touch03_Threshold) > 2)
  {
    Touch03_Threshold = int(Touch03_Threshold * 1.8);
  }
  Touch05_Value = touchRead(TCH05_PIN);
  if ((Touch05_Value / Touch05_Threshold) > 2)
  {
    Touch05_Threshold = int(Touch05_Threshold * 1.8);
  }

  // //////////////////////////////////
  //     START OF ITERATION LOOP
  // //////////////////////////////////
  //
  // Iterate 0 to 254
  for (int i = 0; i < 255; i++)
  {
    // Set position value to iteration value
    int pos = i;

    // DEBUG - Print current Iteration value to serial console for troubleshooting
    if (DebugSerial >= 2)
    {
      Serial.print(" Iteration=");
      Serial.print(i);
      Serial.print(" Pos=");
      Serial.print(pos);
    }

    // **********
    // TOUCH
    // **********
    //
    // Read Touch Values
    Touch01_Value = touchRead(TCH01_PIN);
    Touch03_Value = touchRead(TCH03_PIN);
    Touch05_Value = touchRead(TCH05_PIN);
    //
    // **********
    // TCH01
    // **********
    //
    // Do Stuff If We Detect a Touch on TCH01_PIN
    if (Touch01_Value < Touch01_Threshold)
    {
      // DEBUG - Print current Touch value/threshold to serial console for troubleshooting
      if (DebugSerial >= 2)
      {
        Serial.print(" T1_TCH=");
        Serial.print(Touch01_Value);
        Serial.print("/");
        Serial.print(Touch01_Threshold);
        Serial.print("-");
        Serial.print(Touch01_IntCount);
        Serial.print("/");
        Serial.print(Touch01_LoopCount);
      }
      // STUFF - TCH01_PIN TOUCHED
      if (Touch01_IntFlag == 0)
      {
        // Put stuff to happen once per iteration loop here
        Touch01_IntFlag = 1;
        //
        // *** Add more stuff here if needed ***
        //
      }
      // Put stuff to happen every iteration here
      Touch01_IntCount++;
      //
      // *** Add more stuff here if needed ***
      title_neo_blue();
      //
      // Do Stuff If We DONT Detect a Touch on TCH01_PIN
    }
    else
    {
      // DEBUG - Print current Touch value/threshold to serial console for troubleshooting
      if (DebugSerial >= 2)
      {
        Serial.print(" T1=");
        Serial.print(Touch01_Value);
        Serial.print("/");
        Serial.print(Touch01_Threshold);
        Serial.print("-");
        Serial.print(Touch01_IntCount);
        Serial.print("/");
        Serial.print(Touch01_LoopCount);
      }
      // STUFF - TCH01_PIN NOT TOUCHED
      if (Touch01_IntCount > 1)
      {
        Touch01_IntCount--;
      }
      else
      {
        Touch01_IntCount = 0;
      }
      //
      // *** Add more stuff here if needed ***
      //
    }
    //
    // **********
    // TCH03
    // **********
    //
    // Do Stuff If We Detect a Touch on TCH03_PIN
    if (Touch03_Value < Touch03_Threshold)
    {
      // DEBUG - Print current Touch value/threshold to serial console for troubleshooting
      if (DebugSerial >= 2)
      {
        Serial.print(" T3_TCH=");
        Serial.print(Touch03_Value);
        Serial.print("/");
        Serial.print(Touch03_Threshold);
        Serial.print("-");
        Serial.print(Touch03_IntCount);
        Serial.print("/");
        Serial.print(Touch03_LoopCount);
      }
      // STUFF - TCH03_PIN TOUCHED
      if (Touch03_IntFlag == 0)
      {
        // Put stuff to happen once per iteration loop here
        Touch03_IntFlag = 1;
        //
        // *** Add more stuff here if needed ***
        //
        //
      }
      // Put stuff to happen every iteration here
      Touch03_IntCount++;
      //
      // *** Add more stuff here if needed ***
      title_neo_blue();
      // Do Stuff If We DONT Detect a Touch on TCH03_PIN
    }
    else
    {
      // DEBUG - Print current Touch value/threshold to serial console for troubleshooting
      if (DebugSerial >= 2)
      {
        Serial.print(" T3=");
        Serial.print(Touch03_Value);
        Serial.print("/");
        Serial.print(Touch03_Threshold);
        Serial.print("-");
        Serial.print(Touch03_IntCount);
        Serial.print("/");
        Serial.print(Touch03_LoopCount);
      }
      // STUFF - TCH03_PIN NOT TOUCHED
      if (Touch03_IntCount > 1)
      {
        Touch03_IntCount--;
      }
      else
      {
        Touch03_IntCount = 0;
      }
      //
      // *** Add more stuff here if needed ***
      //
    }
    //
    // **********
    // TCH05
    // **********
    //
    // Do Stuff If We Detect a Touch on TCH05_PIN
    if (Touch05_Value < Touch05_Threshold)
    {
      // DEBUG - Print current Touch value/threshold to serial console for troubleshooting
      if (DebugSerial >= 2)
      {
        Serial.print(" T5_TCH=");
        Serial.print(Touch05_Value);
        Serial.print("/");
        Serial.print(Touch05_Threshold);
        Serial.print("-");
        Serial.print(Touch05_IntCount);
        Serial.print("/");
        Serial.print(Touch05_LoopCount);
      }
      // STUFF - TCH05_PIN TOUCHED
      if (Touch05_IntFlag == 0)
      {
        // Put stuff to happen once per iteration loop here
        Touch05_IntFlag = 1;
        //
        // *** Add more stuff here if needed ***
        //
      }
      // Put stuff to happen every iteration here
      Touch05_IntCount++;
      //
      // *** Add more stuff here if needed ***
      digitalWrite(LED_D2, HIGH);
      //
      // Do Stuff If We DONT Detect a Touch on TCH05_PIN
    }
    else
    {
      // DEBUG - Print current Touch value/threshold to serial console for troubleshooting
      if (DebugSerial >= 2)
      {
        Serial.print(" T5=");
        Serial.print(Touch05_Value);
        Serial.print("/");
        Serial.print(Touch05_Threshold);
        Serial.print("-");
        Serial.print(Touch05_IntCount);
        Serial.print("/");
        Serial.print(Touch05_LoopCount);
      }
      // STUFF - TCH05_PIN NOT TOUCHED
      if (Touch05_IntCount > 1)
      {
        Touch05_IntCount--;
      }
      else
      {
        Touch05_IntCount = 0;
      }
      //
      // *** Add more stuff here if needed ***
      digitalWrite(LED_D2, LOW);
      //
    }

    // ********************
    // ITERATION POS GROUPS
    // ********************
    //
    // First of three position groups i 0-84
    if (pos < 85)
    {
      //
      if (pos == 0)
      {
        cameraShutter1();
        // cameraShutter2();
      }
      //
      // LED FUNCTIONS
      title_neo_colorshift(pos, 1);
      ledPwmSet(pos, 1);
      BI_blink_one(pos);
      // Second of three position groups i 85-169 (pos-85 = 0-84)
    }
    else if (pos < 170)
    {
      pos = pos - 85;
      //
      if (pos == 0)
      {
        // cameraShutter1();
        cameraShutter2();
      }
      //
      // LED FUNCTIONS
      title_neo_colorshift(pos, 2);
      ledPwmSet(pos, 2);
      BI_blink_one(pos);
      // Third of three position groups i 170-254 (pos-170 = 0-84)
    }
    else
    {
      pos = pos - 170;
      //
      // LED FUNCTIONS
      title_neo_colorshift(pos, 3);
      BI_blink_one(pos);
      // Split third group 3/4 (pos 0-42) for even number of transitions
      if (pos < 43)
      {
        //
        ledPwmSet(pos, 3);
        // Split third group 4/4 (pos 43-84) for even number of transitions
      }
      else
      {
        //
        ledPwmSet(pos, 4);
      }
    }

    // DEBUG - Print status neopixel mode
    if (DebugSerial >= 2)
    {
      Serial.print(" Smode=");
      Serial.print(status_neo_mode);
    }

    // DEBUG - Print Carriage Return for iteration level debug output
    if (DebugSerial >= 2)
    {
      Serial.println();
    }

    // Pause the loop to display everything
    delay(LEDDelayTime);

    // Turn OFF White LED at end of Iteration loop
    digitalWrite(LED_D2, LOW);

    // END OF FOR ITERATION LOOP
  }
  // //////////////////////////////////
  //     END OF ITERATION LOOP
  // //////////////////////////////////

  // Touch Loop Counters
  if (Touch01_IntCount >= 1)
  {
    Touch01_LoopCount++;
    Touch01_IntCount = 0;
  }
  else
  {
    Touch01_LoopCount = 0;
  }
  if (Touch03_IntCount >= 1)
  {
    Touch03_LoopCount++;
    Touch03_IntCount = 0;
  }
  else
  {
    Touch03_LoopCount = 0;
  }
  if (Touch05_IntCount >= 1)
  {
    Touch05_LoopCount++;
    Touch05_IntCount = 0;
  }
  else
  {
    Touch05_LoopCount = 0;
  }

  // Reset Touch Iteration Flags
  Touch01_IntFlag = 0;
  Touch03_IntFlag = 0;
  Touch05_IntFlag = 0;

  // Turn off all LEDs at end of loop (Optional for troubleshooting)
  // ledAllOff();

  // //////////////////////////////////////////////////
  //
  // Launch DEAUTH SNIFF Alternate Mainline Code When
  // Touch01_LoopCount exceeds Touch01_Loop_Threshold
  //
  // //////////////////////////////////////////////////
  if (Touch01_LoopCount > Touch01_Loop_Threshold)
  {
    Serial.println("LONG TOUCH DETECTED on TCH01 - JUMP TO ALTERNATE CODE");
    ledAllOff();
    title_neo_red();
    // Print Serial Welcome Once
    Serial.println("****************************************");
    Serial.println("****************************************");
    Serial.println("** WELCOME TO WIFI DEAUTH SNIFF MODE ***");
    Serial.println("****************************************");
    Serial.println("****************************************");
    Serial.println("*** ACTIVATED BY LONG TOUCH ON TCH01 ***");
    Serial.println("****************************************");
    Serial.println("****************************************");
    Serial.println("** LONG PRESS AGAIN TO EXIT THIS MODE **");
    Serial.println("****************************************");
    Serial.println("****************************************");
    // Pause before turning on proceeding
    delay(1000);
    //
    // DEAUTH SNIFF SETUP
    deauth_sniff_setup();
    // Pause for WiFi to come up
    delay(2000);
    //
    // DEAUTH SNIFF Alternative Main Loop
    while (deauth_sniff_active)
    {
      if (millis() - previousChannelHopTime >= CHANNEL_HOP_INTERVAL)
      {
        if (deauthCount >= deauthThreshold)
        {
          tft.fillScreen(0xF800); // Red background
          tft.setCursor(35, 60);
          tft.setTextColor(GC9A01A_BLACK);
          tft.setTextSize(2);
          tft.println("Detected!");

          tft.setCursor(35, 100);
          tft.setTextColor(GC9A01A_BLACK);
          tft.setTextSize(2);
          tft.print("Channel: ");
          tft.println(currentChannel);

          tft.setCursor(35, 140);
          tft.setTextColor(GC9A01A_BLACK);
          tft.setTextSize(2);
          tft.print("Deauths: ");
          tft.println(deauthCount > 9999 ? 9999 : deauthCount); // Limit to 4 digits

          delay(3500);
          tft.fillScreen(0x07E0); // Reset to green
        }
        Serial.println("Channel - " + String(currentChannel) + " :: Deauths - " + String(deauthCount)); // This will not be the exact number printed on the screen as RX CB is continous
        channelHop();
        previousChannelHopTime = millis();

        tft.fillScreen(0x07E0); // Green background
        tft.setCursor(35, 60);
        tft.setTextColor(GC9A01A_BLACK);
        tft.setTextSize(3);
        tft.println("Scanning...");

        tft.setCursor(35, 100);
        tft.setTextColor(GC9A01A_BLACK);
        tft.setTextSize(2);
        tft.print("Channel: ");
        tft.println(currentChannel);

        if (deauthCount < deauthThreshold)
        {
          tft.setCursor(35, 140);
          tft.setTextColor(GC9A01A_BLACK);
          tft.setTextSize(2);
          tft.print("Deauths: ");
          tft.println(deauthCount);
        }

        // Touch for exit mode settings
        Touch01_Value = touchRead(TCH01_PIN);
        if (Touch01_Value < Touch01_Threshold)
        {
          if (DebugSerial >= 2)
          {
            Serial.print("TCH01_TOUCHED=");
            Serial.print(Touch01_Value);
            Serial.print("/");
            Serial.println(Touch01_Threshold);
          }
          Touch01_LoopCount++;
        }
        else
        {
          Touch01_LoopCount = 0;
        }
        if (Touch01_LoopCount > 3)
        {
          deauth_sniff_active = false;
        }
      }
    }
    // END ALTERNATE MAIN LOOP
    Serial.println("****************************************");
    Serial.println("**** EXITING WIFI DEAUTH SNIFF MODE ****");
    Serial.println("****************************************");
    ledAllOff();
    // Turn Off WiFi/BT
    if (DebugSerial >= 2)
    {
      Serial.println("Turn Off WiFi / BlueTooth");
    }
    setModemSleep();
    Touch01_LoopCount = 0;
    // Pause before turning on proceeding
    delay(100);
  }
  // //////////////////////////////////////////////////
  //
  // Launch WOF Alternate Mainline Code When
  // Touch03_LoopCount exceeds Touch03_Loop_Threshold
  //
  // //////////////////////////////////////////////////
  if (Touch03_LoopCount > Touch03_Loop_Threshold)
  {
    Serial.println("LONG TOUCH DETECTED on TCH03 - JUMP TO WOF SCAN MODE");
    ledAllOff();
    title_neo_red();

    flipper_scan_setup();

    // Start WOF scanning loop
    while (flipper_scan_active)
    {
      Serial.println("Scanning for Flippers...");
      flipperCount = 0; // Reset count before each scan
      BLEScanResults foundDevices = pBLEScan->start(SCAN_TIME, false);
      pBLEScan->clearResults(); // Flush results before next scan

      tftBlack();
      tft.setCursor(35, 60);
      tft.setTextColor(GC9A01A_WHITE);
      tft.setTextSize(3);
      tft.println("Flippers");

      tft.setCursor(35, 100);
      tft.setTextColor(GC9A01A_WHITE);
      tft.setTextSize(3);
      tft.println("Nearby");

      tft.setCursor(35, 140);
      tft.setTextColor(GC9A01A_WHITE);
      tft.setTextSize(3);
      tft.println(flipperCount > 9999 ? 9999 : flipperCount); // Limit to 4 digits

      // Delay before the next scan
      delay(5000); // 5 seconds delay

      // Check for exit mode touch
      Touch03_Value = touchRead(TCH03_PIN);
      if (Touch03_Value < Touch03_Threshold)
      {
        Touch03_LoopCount++;
      }
      else
      {
        Touch03_LoopCount = 0;
      }

      // Exit WOF scan mode if long touch detected
      if (Touch03_LoopCount > Touch03_Loop_Threshold)
      {
        Serial.println("LONG TOUCH DETECTED on TCH03 - EXITING WOF SCAN MODE");
        flipper_scan_active = false; // Exit the scanning loop
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

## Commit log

2023-09-28 BTV Gerbers from EasyEDA
2023-12-28 initial badge template
    [BatteryHolder_2466_1xAAA.step, BatteryHolder_2468_2xAAA.step, Battery_Holder_3xAAA_Simple.step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]
2024-02-16 eda updates
    [GC9A01_1.28IN_240x240_v1.step, camera_badge.kicad_pcb, camera_badge.kicad_sch]
2024-02-20 eda conversion to KiCad v7
    [camera_badge.kicad_pcb, camera_badge.kicad_sch]
2024-02-21 badge eda updates
    [camera_badge.kicad_pcb, camera_badge.kicad_sch]
2024-02-22 eda update
    [camera_badge.kicad_pcb]
2024-03-13 made badge wider
    [camera_badge.kicad_pcb]
2024-03-14 art and fotprint and pcb updates
    [camera_badge.kicad_pcb]
2024-03-18 added ESP32 Wemos Lolin32 Lite schem footprints 3D
2024-03-22 updated arduino version and recompiled code
2024-03-25 footprint and schem updates
    [camera_badge.kicad_pcb, camera_badge.kicad_sch]
2024-03-25 footprint and schematic updates
    [camera_badge.kicad_sch]
2024-03-26 schematic update
    [camera_badge.kicad_sch]
2024-03-27 pcb work
    [camera_badge.kicad_pcb, camera_badge.kicad_sch]
2024-03-27 pcb updates
    [camera_badge.kicad_pcb]
2024-03-27 pcb trace work
    [camera_badge.kicad_pcb, camera_badge.kicad_sch]
2024-04-02 prototype completed
    [camera_badge-B_Cu.gbl, camera_badge-B_Mask.gbs, camera_badge-B_Paste.gbp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]
2024-04-11 test code for prototype
2024-04-12 pcb rev2 updates
    [camera_badge.kicad_sch]
2024-04-18 second prototype done
    [camera_badge-B_Cu.gbl, camera_badge-B_Mask.gbs, camera_badge-B_Paste.gbp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]
2024-04-29 added deauth sniff to camera_badge_rev01 code
2024-05-06 Component BOM completed
2024-07-18 push camera shutter effect
2024-08-05 Adding Assembly Instructions
2026-07-27 Update BadgeInstructions.md
    edit for possible PH/JST connector with reversed wire colors.

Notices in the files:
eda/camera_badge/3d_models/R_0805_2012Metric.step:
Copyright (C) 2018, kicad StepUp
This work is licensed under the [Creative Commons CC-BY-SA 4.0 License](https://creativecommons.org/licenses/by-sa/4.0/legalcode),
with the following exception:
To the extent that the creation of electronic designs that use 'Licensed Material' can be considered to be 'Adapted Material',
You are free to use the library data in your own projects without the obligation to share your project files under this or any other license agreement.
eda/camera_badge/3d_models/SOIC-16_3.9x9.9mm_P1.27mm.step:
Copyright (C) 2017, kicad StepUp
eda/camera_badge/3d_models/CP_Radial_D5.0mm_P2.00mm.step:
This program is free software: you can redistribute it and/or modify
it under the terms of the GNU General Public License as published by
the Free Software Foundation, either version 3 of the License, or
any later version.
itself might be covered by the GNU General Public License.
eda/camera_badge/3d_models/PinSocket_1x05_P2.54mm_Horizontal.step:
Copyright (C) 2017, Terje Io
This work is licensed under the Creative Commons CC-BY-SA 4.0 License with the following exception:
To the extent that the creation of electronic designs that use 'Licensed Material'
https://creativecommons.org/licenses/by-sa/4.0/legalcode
